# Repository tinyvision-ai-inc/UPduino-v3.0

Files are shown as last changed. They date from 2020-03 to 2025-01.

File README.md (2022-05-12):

# UPduino-v3.0 and 3.1

UPduino v3.0 Front

Image credit: Gregory Benjamin

## UPDuino v3.1: PCB Design Files, Designs, Documentation

The UPDuino v3.1 is a small, low cost FPGA board. The board features an on-board FPGA programmer, flash and LED with _all_ FPGA pins brought out to easy to use 0.1" header pins for fast prototyping.

The tinyVision.ai UPduino v3.x Board Features:

* Lattice UltraPlus ICE40UP5K FPGA with 5.3K LUTs, 1Mb SPRAM, 120Kb DPRAM, 8 Multipliers
* FTDI FT232H USB to SPI Device
* _ALL_ 32 FPGA GPIO on 0.1” headers
* 4MB SPI Flash
* RGB LED
* On board 3.3V and 1.2V Regulators, can supply 3.3V to your project
* Open source schematic and layout using KiCAD design tools
* Integrated into the open source [APIO toolchain](https://github.com/FPGAwars/apio)
* Works with [IceStudio](https://github.com/FPGAwars/icestudio)<sup>[nightly/dev branch only at the moment](https://downloads.icestudio.io/)</sup>

Please see the [wiki page](https://github.com/tinyvision-ai-inc/UPduino-v3.0/wiki) for the changes that were implemented from v2.1. Some salient features are:
* 4 layer board with a solid ground plane, proper layout/decoupling for good signal integrity and FPGA operation
* Access to on-board 12MHz oscillator using a jumper
* _All_ FPGA pins including LED driver pins are brought to 0.1" headers
* qSPI Flash capable
* tinyFPGA bootloader compatible 

Here are some resources for you:
* [Documentation](https://upduino.readthedocs.io/) (beyond what's on this GitHub)
* [Discord channel](https://discord.gg/3qbXujE)
* [Schematic](./Board/v3.0/UPduino_v3.0.pdf)
* [AssemblyDrawing](./Board/v3.0/UPduino_v3.0Assembly.html)
* [Blinking LED](./RTL/blink_led)
 
TinyVision.ai blog posts:
* [Magic Smoke and PTC's](https://blogs.tinyvision.ai/upduino/power/ptc/2021/12/31/magic-smoke-and-PTCs.html)
* [Lattice Modelsim on Windows](https://blogs.tinyvision.ai/modelsim/windows/linux/radiant/lattice/2022/01/01/Using-Lattice-Modelsim-on-Win-Linux.html)
* [Ground trampolines and Phase Locked Loops](https://tinyvision.ai/blogs/processing-at-the-edge/ground-trampolines-and-phase-locked-loops)

You can buy this board here:
US and non-EU orders: . 

EU Orders with VAT paid: 

For expedited shipping options, please visit the storefront at www.tinyvision.ai or email us directly at: sales at tinyvision dot ai.

## Useful links
* [Digi-Key Intro to FPGA Video series](https://youtube.com/playlist?list=PLEBQazB0HUyT1WmMONxRZn9NmQ_9CIKhb)
* [osresearch](https://github.com/osresearch/up5k): large collection of very useful code and a good overview.
* [UPduino FPGA tutorial using APIO](https://blog.idorobots.org/entries/upduino-fpga-tutorial.html)
* [A very detailed blog on implementing a RISCV in the FPGA](https://pingu98.wordpress.com/2019/04/08/)
* [Lattice iCECube2 tutorial](https://hsel.co.uk/2018/05/21/lattice-ice40-ultra-plus-fpga-gnarly-grey-upduino-tutorial-1-the-basics/)
* [Open FPGA verilog Tutorial](https://github.com/Obijuan/open-fpga-verilog-tutorial/wiki)

## The next generation of Upduino (coming soon)
* [pico-ice](https://github.com/tinyvision-ai-inc/pico-ice)

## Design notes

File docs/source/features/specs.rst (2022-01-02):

Specifications
================

The UPduino supports the following features:
  - Lattice iCE40 UP5K UG48 FPGA

UPduino Pinout
--------------
The UPduino pinout was kindly provided by Xark below.
  - G0/G1/G3/G6 refer to Global clock inputs.
  - gpio_20 is used for the on-board 12MHz oscillator if the OSC jumper is shorted.
  - gpio_35 is the ideal location to supply a clock as this will allow placement of the PLL right next to it.
  - If gpio_35 is used as an input, y nything other than a clock, you cannot use a PLL in your design!
  - qSPI flash access is possible by shorting the jumpers on the board: note that this uses up gpio_10 and gpio_20.
::

                  PCF  Pin#  _____  Pin#  PCF
                       ------| USB |------
                 <GND> |  1   \___/   48 | spi_ssn   (16)
                 <VIO> |  2           47 | spi_sck   (15)
                 <RST> |  3           46 | spi_mosi  (17)
                <DONE> |  4           45 | spi_miso  (14)
      <RGB2>   led_red |  5           44 | gpio_20   <N/A w/OSC, G3>
      <RGB0> led_green |  6     U     43 | gpio_10
      <RGB1>  led_blue |  7     P     42 | <GND>
                 <+5V> |  8     D     41 | <12 MHz>
               <+3.3V> |  9     U     40 | gpio_12
                 <GND> | 10     I     39 | gpio_21
               gpio_23 | 11     N     38 | gpio_13
               gpio_25 | 12     O     37 | gpio_19
               gpio_26 | 13           36 | gpio_18
               gpio_27 | 14     V     35 | gpio_11
               gpio_32 | 15     3     34 | gpio_9
      <G0>     gpio_35 | 16     .     33 | gpio_6
               gpio_31 | 17     0     32 | gpio_44   <G6>
      <G1>     gpio_37 | 18           31 | gpio_4
               gpio_34 | 19           30 | gpio_3
               gpio_43 | 20           29 | gpio_48
               gpio_36 | 21           28 | gpio_45
               gpio_42 | 22           27 | gpio_47
               gpio_38 | 23           26 | gpio_46
               gpio_28 | 24           25 | gpio_2
                       -------------------

Errata
======
Please note that the silkscreen on the UPduino 3.0 has a bug. The GND and 12MHz clock pins are exchanged.
(Pins 41 and 42 in the drawing above). The drawing above is correct and the silkscreen is wrong for these
2 pins.

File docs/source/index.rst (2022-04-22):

.. this is a comment, it is not rendered
   when adding new *.rst files, reference them here
   in this index.rst for them to be rendered and added to the
   table of contents

=====================
UPduino Documentation
=====================

tinyVision.ai
*************

UPDuino v3.0: PCB Design Files, Designs, Documentation
------------------------------------------------------

The UPDuino v3.0 is a small, low-cost FPGA board. The board features an on-board FPGA programmer, flash and LED with _all_ FPGA pins brought out to easy to use 0.1" header pins for fast prototyping.

The tinyVision.ai UPduino v3.0 Board Features:

* Lattice UltraPlus ICE40UP5K FPGA with 5.3K LUTs, 1Mb SPRAM, 120Kb DPRAM, 8 Multipliers
* FTDI FT232H USB to SPI Device
* _ALL_ 32 FPGA GPIO on 0.1” headers
* _ALL_ FTDI pins brought to test points
* 4MB SPI Flash
* RGB LED
* On board 3.3V and 1.2V Regulators, can supply 3.3V to your project
* Open source schematic and layout using KiCAD design tools
* Integrated into the open source `APIO toolchain <https://github.com/FPGAwars/apio>`_

Please see the `wiki page <https://github.com/tinyvision-ai-inc/UPduino-v3.0/wiki>`_  for the changes that were implemented from v2.1. Some salient features are:

* 4 layer board with a solid ground plane, proper layout and decoupling for good signal integrity and FPGA operation
* Access to on-board 12MHz oscillator using a jumper (short R16)
* _All_ FPGA pins including LED driver pins are brought to 0.1" headers
* qSPI flash capability
* tinyFPGA bootloader compatible

Useful links:

* `osresearch <https://github.com/osresearch/up5k>`_: large collection of very useful code and a good overview.
* `UPduino FPGA tutorial using APIO <https://blog.idorobots.org/entries/upduino-fpga-tutorial.html>`_
* `A very detailed blog on implementing a RISCV in the FPGA <https://pingu98.wordpress.com/2019/04/08/>`_
* `Digi-Key FPGA Playlist <https://youtube.com/playlist?list=PLEBQazB0HUyT1WmMONxRZn9NmQ_9CIKhb>`_: "What is an FPGA" all the way to designing a risc-v custom peripheral in just 12 videos filled with great tutorials, links, and explanations.

TinyVision.ai blog posts:

* `Magic Smoke and PTC's <https://blogs.tinyvision.ai/upduino/power/ptc/2021/12/31/magic-smoke-and-PTCs.html>`_
* `Lattice Modelsim on Windows <https://blogs.tinyvision.ai/modelsim/windows/linux/radiant/lattice/2022/01/01/Using-Lattice-Modelsim-on-Win-Linux.html>`_
* `Ground trampolines and Phase Locked Loops <https://tinyvision.ai/blogs/processing-at-the-edge/ground-trampolines-and-phase-locked-loop>`_

.. toctree::
   :hidden:

   self
   
.. toctree::
   :maxdepth: 2
   :caption: Introduction
   :hidden:

   introduction/introduction

.. toctree::
   :maxdepth: 2
   :caption: Getting Started
   :hidden:

   getting_started/tool_installation
   getting_started/first_steps
   getting_started/verilog_resources
   
.. toctree::
   :maxdepth: 2
   :caption: Features
   :hidden:

   features/specs
   
.. toctree::
   :maxdepth: 2
   :caption: Tutorials
   :hidden:
   
   tutorials/blink_led.rst
   tutorials/bank_voltages
   tutorials/oscillator
   tutorials/disconnect_tricolor_led
   tutorials/fpga_sram_programming
   tutorials/qspi_flash
   tutorials/tinyfpga
   tutorials/riscv
   tutorials/open_ocd
   tutorials/pmod
   tutorials/adding_slave_select_to_fpga

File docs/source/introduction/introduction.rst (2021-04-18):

Introduction
============

The UPduino 3.0 is a highly capable device. We will get started with setting it up, and the "hello world" of this FPGA, getting an LED to blink!

First Steps
-----------

First things first, after ensuring your board is functioning and shows up as a USB device, the tools need to get installed. There are two paths to do:

- APIO or icetools (For MacOS, Linux, and Windows)
- Lattice Radiant (Linux and Windows only)

To install these tools, please go to the "Tool Installation" document!

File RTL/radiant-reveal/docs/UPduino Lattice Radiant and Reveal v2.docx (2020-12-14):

UPduino v3.0 Lattice Radiant and Reveal v2.2 Setup With Debug Cable

The following document is a quick set-up guide for the UPduino v3.0 FPGA programming board. The purpose of this document is to show how to set up the RGB blinky verilog file with the Lattice v2.2 toolchain plus running an example debug session using the Reveal v2.2 tools.

All files and example project files have been provided – it could be necessary to change some of the files to fit the directory structure the examples are downloaded/cloned into – this is OS and tool dependent to some extent. The demo programs here were all run under Win10-64.

It is assumed the UPduino v3.0 git repository has been downloaded to a local directory as well as what is contained in this demo document and the corresponding directories. To get started under Radiant – it is necessary to set up a project and to make some small changes to the rgb_blink.v file – if you have downloaded/cloned the files – but if you are following along and want to make your own local changes – diagrams/pictures have been provided that will hopefully make it easy. If you haven’t gone through the Lattice tutorial document – it will more than likely be helpful to take a look at that – plus it will be referenced in this document a few times - Lattice Radiant Software Tutorial for iCE40 UltraPlus¹ – the download link is here (if this can’t be found – then ‘google’ the title):
https://www.latticesemi.com/media/LatticeSemi/Documents/InstallationGuides/Radiant20_Tutorial_ice40.ashx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

Please refer to the above tutorial for the finer details on creating a new project – it would be good to review even if you have cloned the project and are trying to run it for the first time. If you have cloned the project and the assumption is that you have – the project you want to open is:

<your dir>/UPduino-v3.0/RTL/Lattice-Radiant-Project-v2p2/rgb_blinky/rgb_blinky.rdf

The first thing to note are a few changes are necessary to run the RGB demo code:

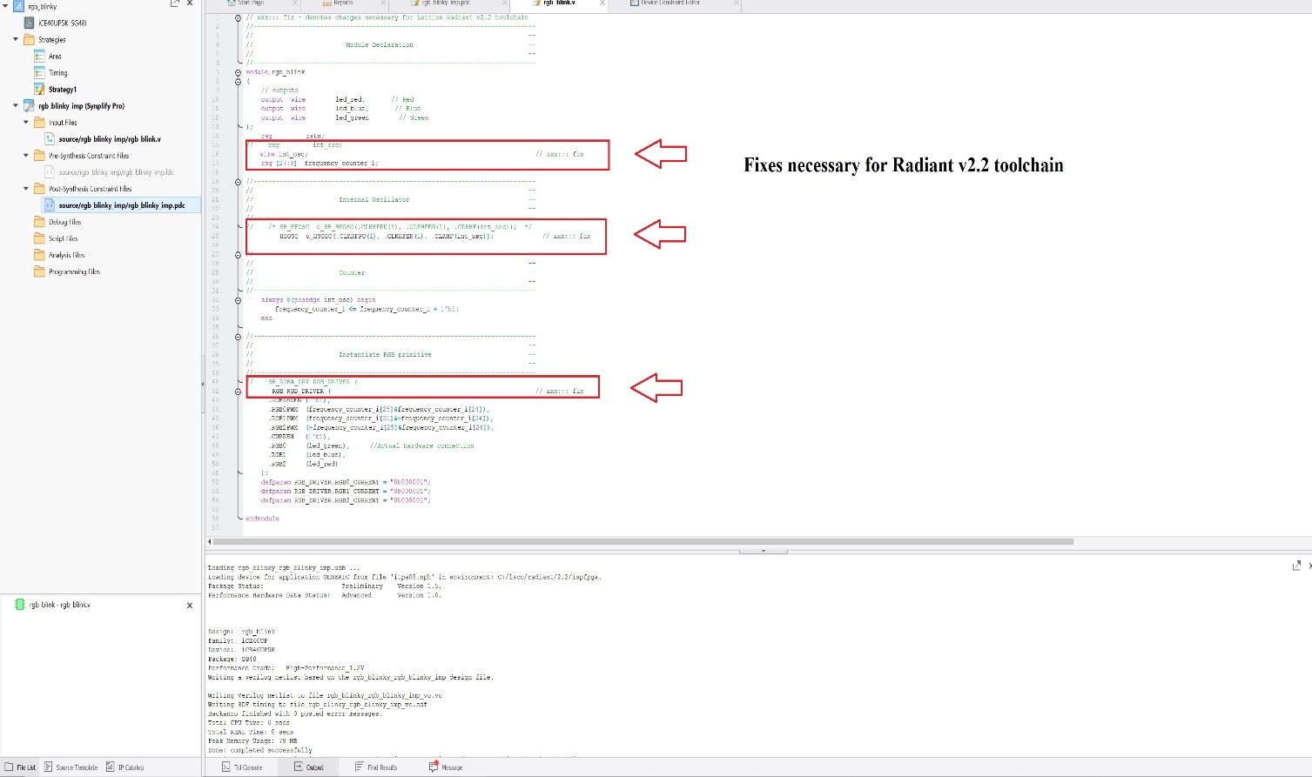
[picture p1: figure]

Figure 1 – Necessary verilog updates to run demo program in Lattice Radiant.

Note the changes outlined in Figure 1 are suggestions – but for the purposes of this demo please make sure that your verilog file has those updates or it will not build (under the Lattice Radiant tools).

Please make sure the project builds OK without error. There is an example constraints file included in the example project directory.

We want to be able to run the Reveal debugger – for purposes of this demo, the debug cable used is the FTDI C232HM USB 2.0 HI-SPEED TO MPSSE CABLE².

This cable should be able to be used as received from FTDI – the only real difference I have seen thus far is setting the drive current to 8 milli-amps for the I/O pins. The xml file for the FTDI cable is included in the git repository just in case. The FTDI cable can be viewed here:

https://www.ftdichip.com/Products/Cables/USBMPSSE.htm and PDF:
https://www.ftdichip.com/Support/Documents/DataSheets/Cables/DS_C232HM_MPSSE_CABLE.pdf

Using this cable is cheaper than the HW-USBN-2B³:

https://www.latticestore.com/searchresults/tabid/463/searchid/1/searchvalue/hw-usbn-2b/default.aspx - plus it is available – Mouser P/N: 895-C232HM-DDHSL-0
and current cost is $35.00 (USD) (as an example of a cheaper option).

Please refer to pages 38 - ~ 44 of the tutorial for any questions regarding the following – the first step is to add debug logic to our design using the Reveal Inserter:

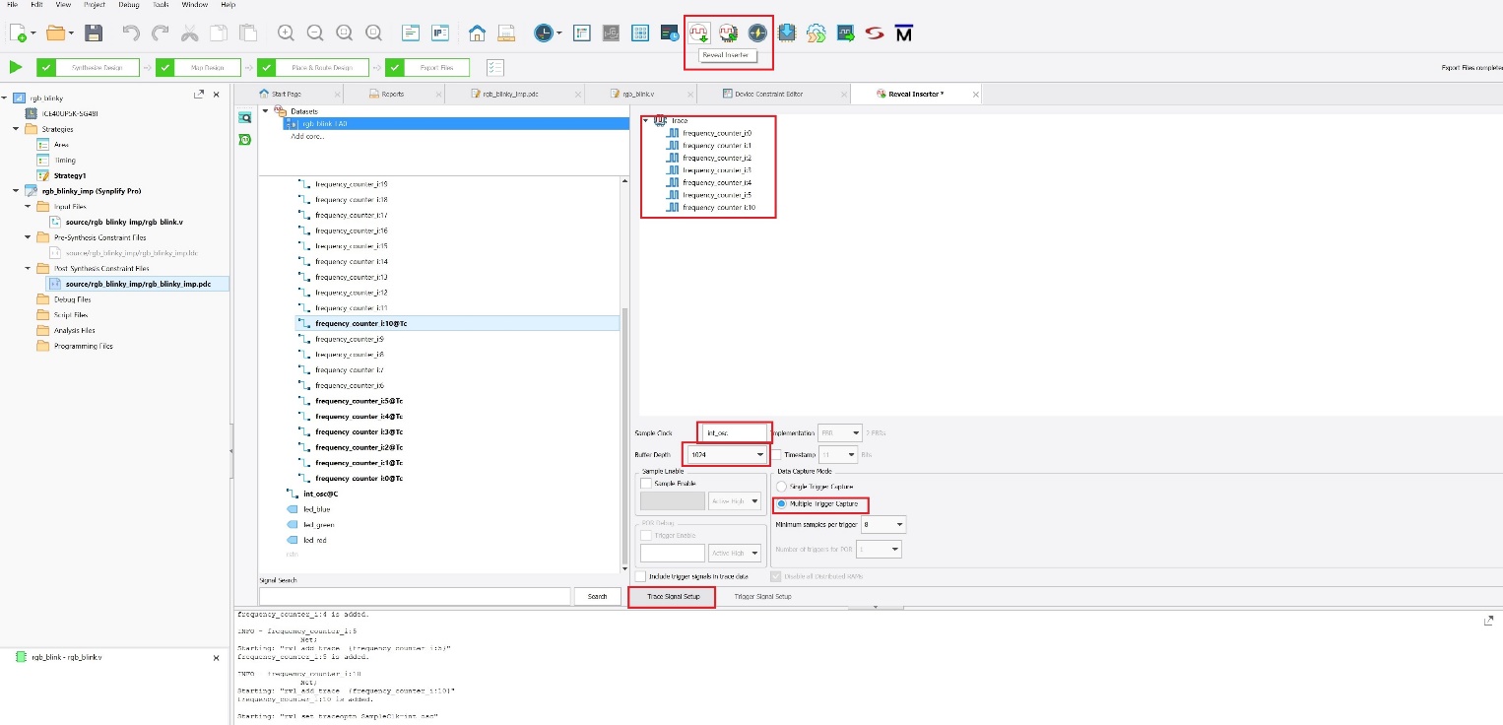
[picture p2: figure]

Figure 2 – Using Reveal Inserter to add on-chip Debug Logic.

Once the desired trace signals have been added – trigger signals need to be added:

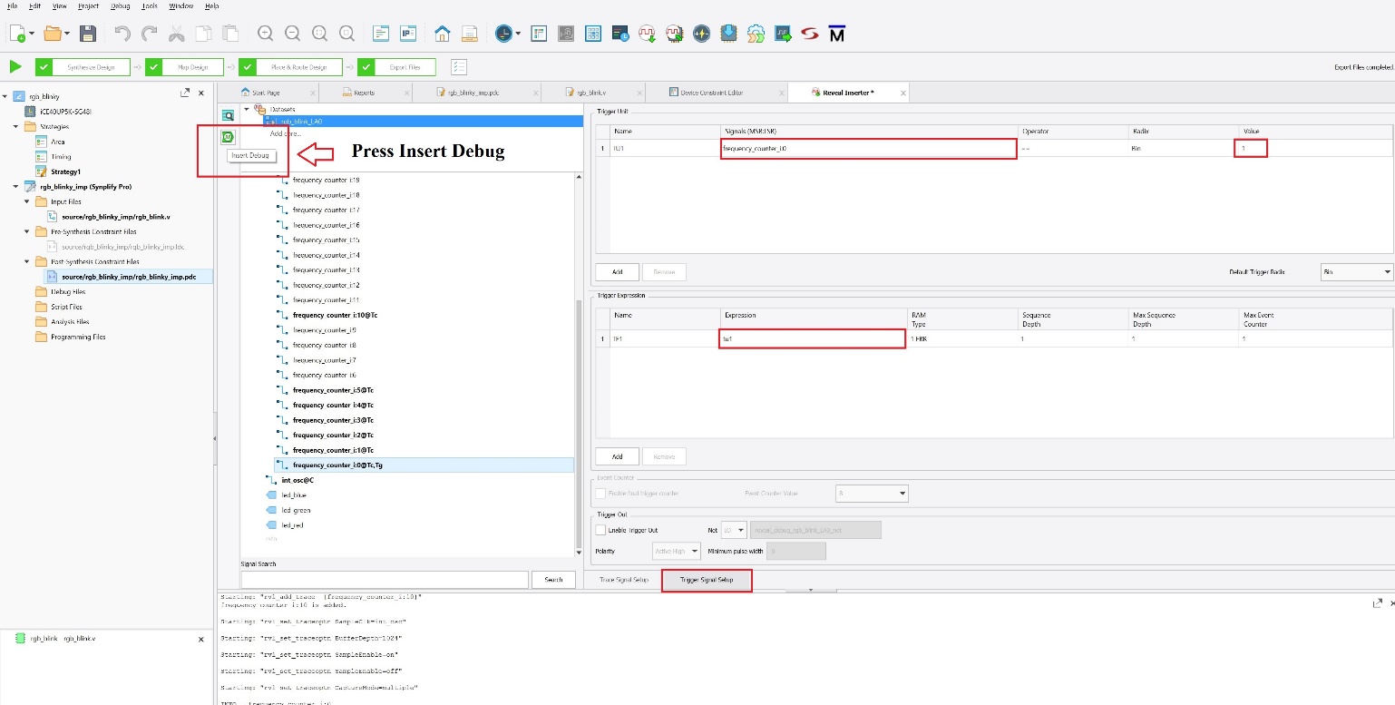
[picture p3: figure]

Figure 3 – Adding trigger signals to the Reveal Inserter set up for on-chip Debug Logic.

To add to the project – press the Insert Debug Icon as shown in Fig. 3.

Once that is added – make sure the project can build. Once the project has built with no errors – then the JTAG connections need to be checked. The Lattice tools will set the JTAG pins even if they are not in the constraints file – but subsequent builds could reassign the pin locations – so it is a good idea to try and lock those down – otherwise you will be moving the JTAG pins every time you make a change and rebuild.

In the Device Constraints Editor – you can type in the pin number to override what the tools have assigned if it does not match the constraints file or what you have used for your JTAG pins. Make sure and connect GND first when connecting the FTDI cable to the UPduino board.

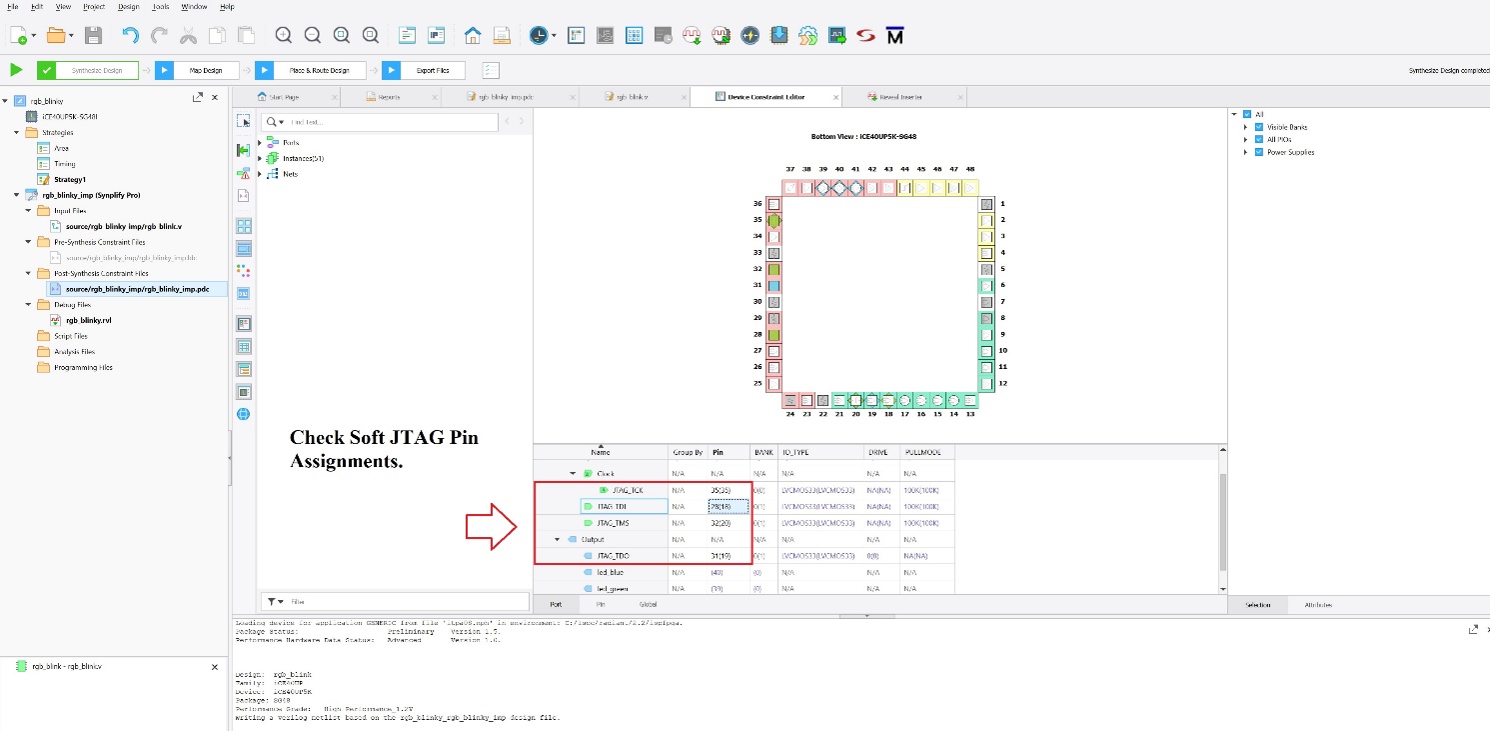
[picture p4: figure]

Figure 4 – Check the Soft JTAG Pin Assignments.

If you must update the JTAG pin assignments – you will have to rebuild to make sure the JTAG pins are assigned to the pin numbers used for the JTAG FTDI cable. Otherwise, a cable server error will appear (when making the connections – we’re not quite ready for this now – but as this is a potential issue – it’s better to bring it up sooner than later) and it’ll tell you to check items 9-1 (Failure Points) in the following document:
Reveal Troubleshooting for Lattice Radiant Software⁴
https://www.latticesemi.com/view_document?document_id=52931

The cable used in this demo is FTDI, UART, MPSSE (Multi-Protocol Synchronous Serial Engine), using the standard VCP driver from FTDI. (Please note document mentioned earlier in this document².) If the proper cable is being used – then errors encountered at this step where Reveal complains about the cable server not being able to open the USB port is more than likely an incorrect JTAG connection – and it can be caused by the tools moving the JTAG ports around if they are not locked down – so double check the JTAG port pin assignments *EVERY* time you build.

Once the project has been built and the pin assignments have been verified and you have connected your debugger –

Note you can refer to P. 43 of the tutorial document for a quick explanation on how to connect the debug cable to a target board – here we are connecting an FTDI cable to the UPduino v3.0 – but the procedure is essentially the same.

The build needs to be downloaded to the target:

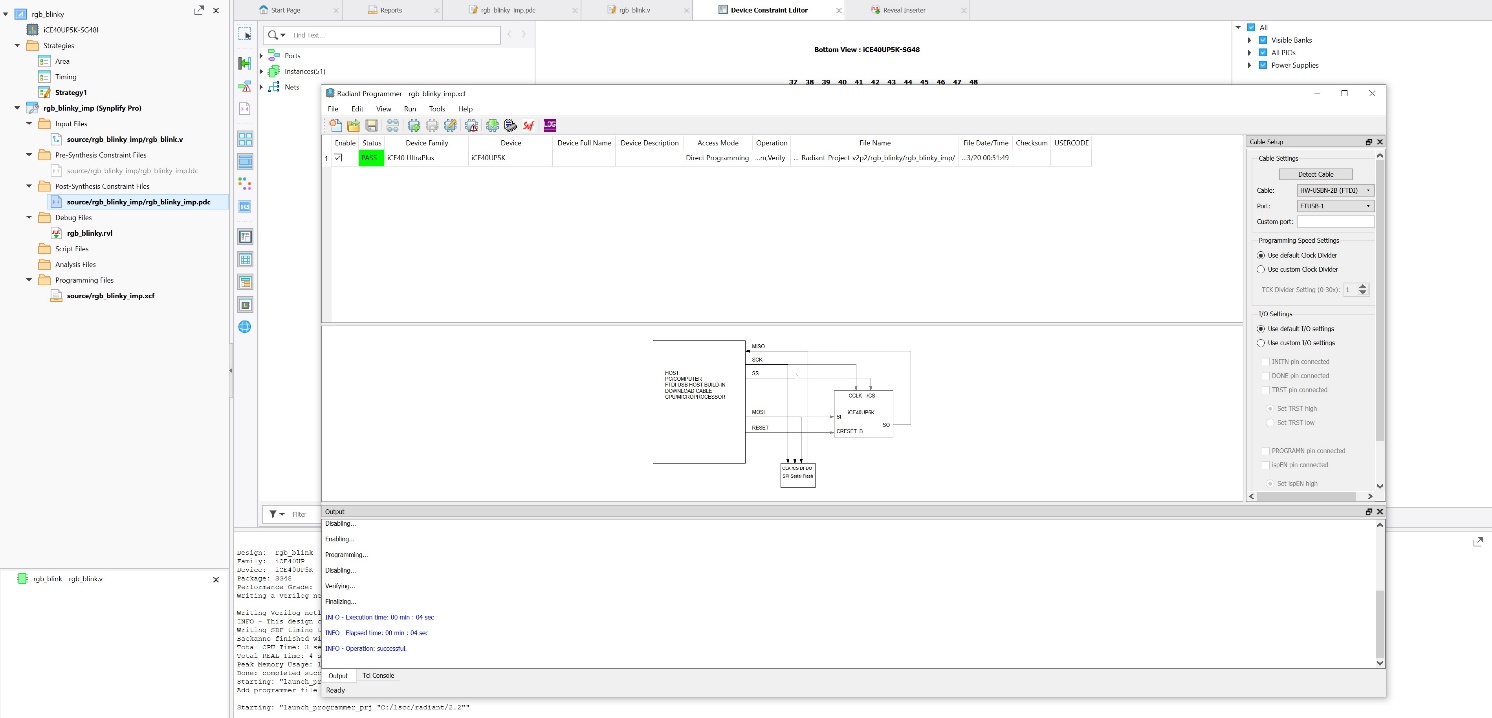
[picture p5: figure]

Figure 5 – Program the target board with the rgb_blink.v build plus on-chip debug logic.

For the next steps you can refer to pages 44 - ~48 of the tutorial document.

Once the target has been programmed – open the Reveal analyzer to create the debug analyzer session:

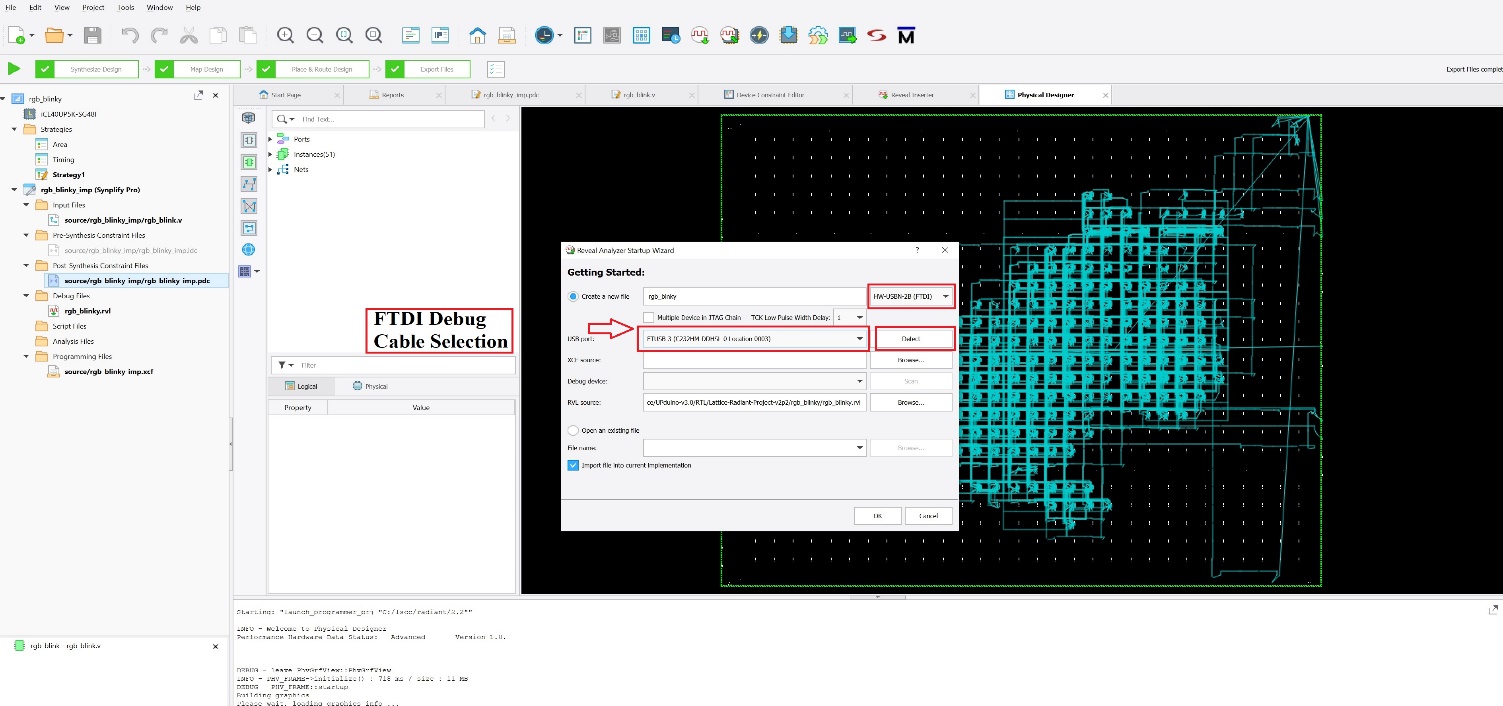
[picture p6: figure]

Figure 6 – Creating Reveal Analyzer Session

Refer to Figure 6 regarding creating the Reveal Analyzer session – make sure the correct FTDI cable is selected for the debug session.

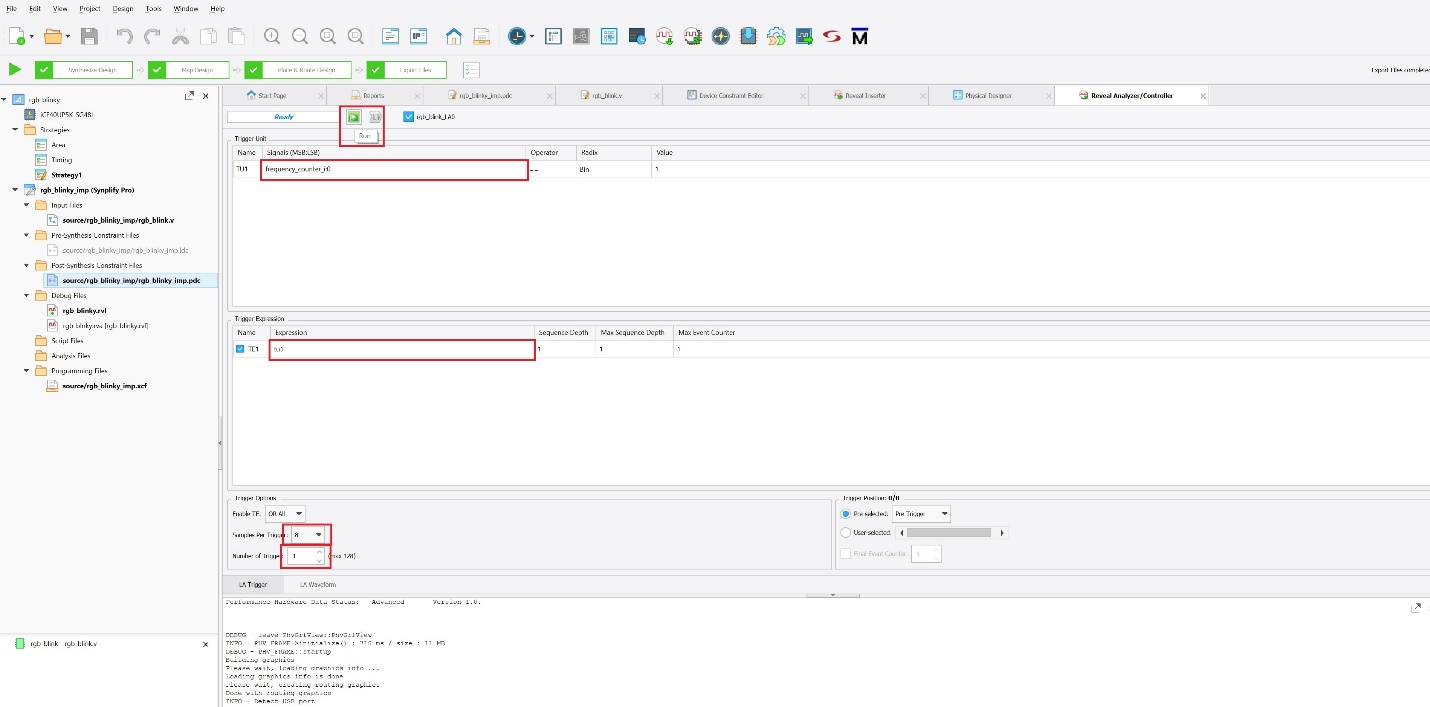
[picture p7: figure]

Figure 7 – Reveal Analyzer Window

Refer to Figure 7 regarding the Reveal Analyzer Window – the green box with the arrow can be pressed to run the analyzer session – note ‘Ready’ should be visible to the left of that window.

If an error pops up – please refer to the troubleshooter link mentioned previously – but errors are more than likely due to incorrect JTAG connections.

Once the Reveal Analyzer runs – you should see something like:

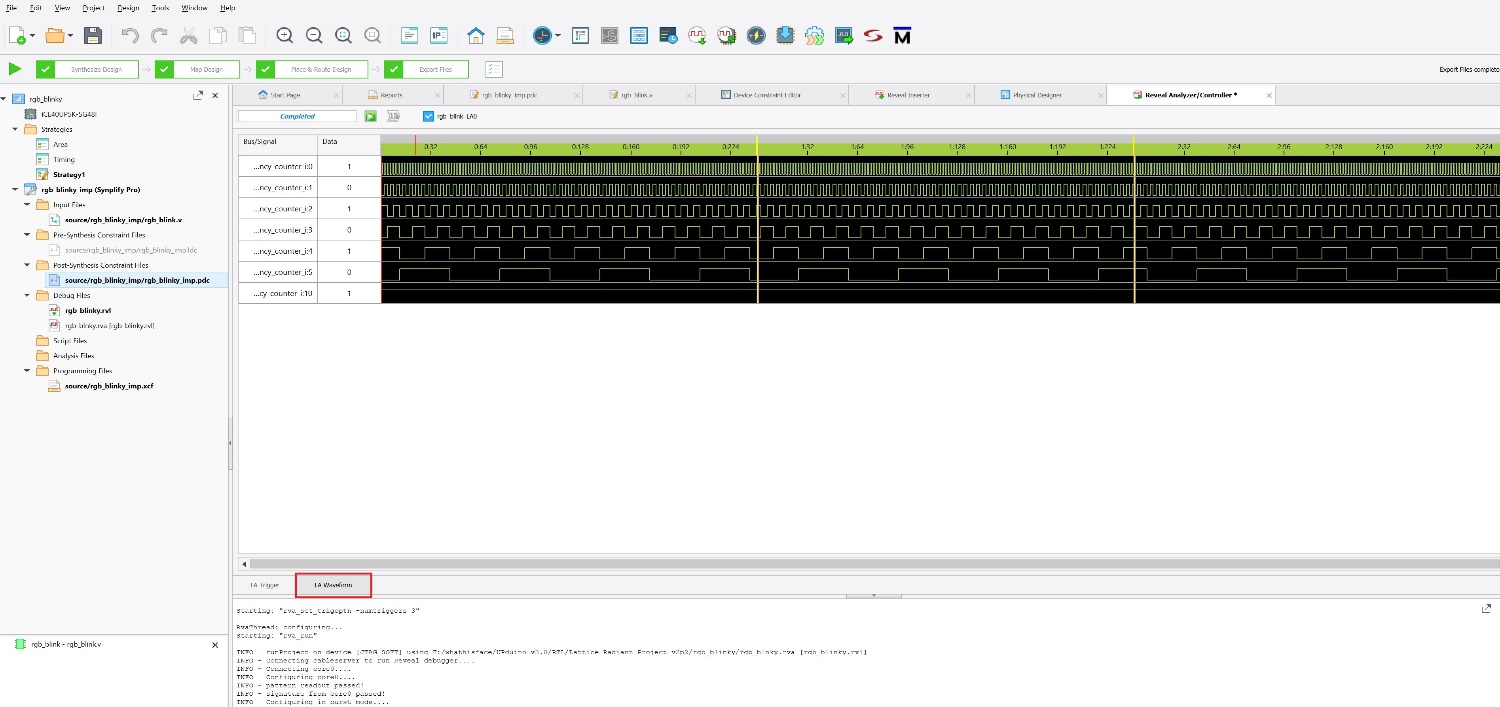
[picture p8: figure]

Figure 8 – Reveal Analyzer Session Results

Hopefully, this brief guide has been helpful in running a JTAG debug session on the UPduino v3.0 FPGA board and will serve as a handy reference.

References:

(1) Lattice Radiant Software Tutorial for iCE40 UltraPlus
https://www.latticesemi.com/media/LatticeSemi/Documents/InstallationGuides/Radiant20_Tutorial_ice40.ashx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

(2) FTDI C232HM USB 2.0 HI-SPEED TO MPSSE CABLE
https://www.ftdichip.com/Products/Cables/USBMPSSE.htm and PDF:
https://www.ftdichip.com/Support/Documents/DataSheets/Cables/DS_C232HM_MPSSE_CABLE.pdf

(3) LATTICE HW-USBN-2B Programmer
https://www.latticestore.com/searchresults/tabid/463/searchid/1/searchvalue/hw-usbn-2b/default.aspx

(4) Reveal Troubleshooting for Lattice Radiant Software
https://www.latticesemi.com/view_document?document_id=52931

whathisface@protonmail.com 2

UPduino v3.0 Lattice Radiant and Reveal v2.2

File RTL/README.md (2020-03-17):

# FPGA build instructions
The FPGA can be built either using the Lattice Radiant toolchain that can be downloaded [here](http://www.latticesemi.com/en/Products/DesignSoftwareAndIP) or the open source icestorm toolchain which can be downloaded [here](https://github.com/cliffordwolf/icestorm).

## Instructions for icestorm toolchain programming
Programming the board using icestorm can be done using the following command:

    iceprog.exe -d i:0x0403:0x6014 <bitfile name>

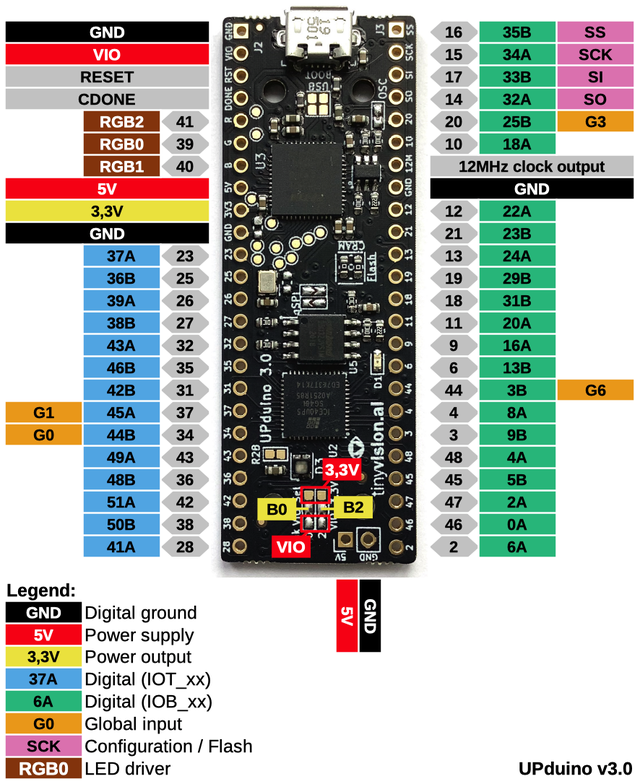
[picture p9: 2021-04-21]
docs/source/features/upduino_pinout.png

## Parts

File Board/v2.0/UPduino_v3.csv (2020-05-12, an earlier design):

Item | Qty | Reference(s) | Value | Footprint | Datasheet | MPN
1 | 13 | C1, C11, C19, C20, C21, C22, C24, C27, C28, C29, C30, C31, C35 | 4.7u | Capacitor_SMD:C_0603_1608Metric | ~
2 | 17 | C2, C3, C5, C6, C7, C8, C9, C10, C12, C13, C14, C15, C16, C17, C18, C25, C36, C4 | 0.1u | Capacitor_SMD:C_0603_1608Metric | ~ | C1005X5R0J104K050BA
5 | 1 | D1 | LTST-C191KGKT | LED_SMD:LED_0603_1608Metric | ~
6 | 1 | D2 | 1N4148WT-7 | Diode_SMD:D_SOD-523 | https://www.vishay.com/docs/85748/1n4148w.pdf
7 | 1 | D3 | CLMVC-FKA-CLBDGL7LBB79353 | VS.preety:LED_Cree-PLCC4_2x2mm_CW | ~
8 | 3 | FB1, FB2, FB3 | BLM18HE152SN1D | Inductor_SMD:L_0603_1608Metric | ~
11 | 1 | J1 | 47589-0001 | vs:USB_Micro_AB_Female_0475890001 | ~
15 | 1 | R1 | 2.2K | Resistor_SMD:R_0603_1608Metric | ~
16 | 1 | R3 | 12K | Resistor_SMD:R_0603_1608Metric | ~
17 | 3 | R4, R17, R18 | 10K | Resistor_SMD:R_0603_1608Metric | ~
18 | 5 | R5, R8, R9, R14, R15 | 10K | Resistor_SMD:R_0603_1608Metric | ~
19 | 1 | R6 | 100 | Resistor_SMD:R_0603_1608Metric | ~
20 | 1 | R7 | 2.2K | Resistor_SMD:R_0603_1608Metric | ~
23 | 2 | R12, R13 | 0 | Resistor_SMD:R_0603_1608Metric | ~
27 | 1 | U1 | 93LC56BT-I/OT | vs:SOT-23-6 | http://ww1.microchip.com/downloads/en/DeviceDoc/20001749K.pdf
28 | 1 | U2 | ICE40UP5K-SG48ITR | Package_DFN_QFN:QFN-48-1EP_7x7mm_P0.5mm_EP5.6x5.6mm | http://www.latticesemi.com/Products/FPGAandCPLD/iCE40Ultra
29 | 1 | U3 | FT232H | vs:QFN-48-1EP_8x8mm_P0.5mm_EP6.2x6.2mm | http://www.ftdichip.com/Products/ICs/FT232H.htm
30 | 1 | U4 | SG-210STF 12.0000ML3 | vs:Oscillator_SMD_Abracon_ASDMB-4Pin_2.5x2.0mm | https://abracon.com/Oscillators/ASDMB.pdf
31 | 1 | U5 | W25Q32JVSSIM | Package_SO:SOIC-8_5.23x5.23mm_P1.27mm | http://www.winbond.com/resource-files/w25q32jv%20revg%2003272018%20plus.pdf
32 | 1 | U6 | AP2127K-3.3 | vs:SOT-23-5 | https://www.diodes.com/assets/Datasheets/AP2127.pdf
33 | 1 | U7 | AP2127K-1.2 | vs:SOT-23-5 | https://www.diodes.com/assets/Datasheets/AP2127.pdf
34 | 1 | U8 | SN74AUP2G125DCUR | Package_SO:VSSOP-8_2.3x2mm_P0.5mm | http://www.ti.com/lit/sg/scyt129e/scyt129e.pdf

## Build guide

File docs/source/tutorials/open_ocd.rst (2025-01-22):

How to use the UPduino as an OpenOCD or JTAG debugger?
====

Please see this repo for details on how to use teh FPGA for level translation as well as a spring loaded pogo adapter that can be used to easily probe a board.

https://github.com/tinyvision-ai-inc/upduino-jtag

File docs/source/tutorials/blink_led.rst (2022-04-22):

Blinking an LED
===============

Blinking an LED on the UPduino 3 is its "hello world"

Getting Started
----

The sample code to blink an LED is built-in to this repository! 

https://github.com/tinyvision-ai-inc/UPduino-v3.0

Go to RTL > blink_led folder, to see the example.

Running the Code
-----------------

The code can easily be run! First, make sure the UPduino is plugged in.

If you want to run the code using icetools (iceprog, specifically), type: ``make``

Then: ``iceprog rgb_blink.bin``

You should see the LED blink!

If you want to use apio, first type: ``apio init --board upduino3``

Then: ``apio verify`` to make sure your code works, and then finally:

``apio build`` and ``apio upload``

The LED should blink now!

Making Changes
--------------

So the LED is (hopefully) blinking now. If you want to change the code or learn how it works, open the rgb_blink.v file

*.v stands for Verilog, a low-level programming language*

The code runs asynchroniously, meaning that multiple lines can run at once on the board.

Anyways, **tinker around with the code!** Some things to do:

  - Make it blink a different color
    - Maybe white? Yellow? A random hex value?
  - Make it blink in a different interval
   - Make it go fast
   - How about slow?
   - Can the LED stay on a solid color?
  - Try different brightness values
    - How bright can it go? How many levels are there?
    - Can you do a "breathing" effect, where the LED eases in and out of brightness?
    
There are endless possibilities with this board! Getting an LED to blink is just the start...

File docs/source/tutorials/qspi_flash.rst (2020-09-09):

How to enable qSPI flash for _much_ higher flash throughput (up to 8x!)
====

The UPduino flash is a qSPI/DTR capable device. ie. it is capable of operating with four IO's instead of a single IO and also using both edges of the clock, effectively giving 8x the bandwidth on the SPI bus. In an actual use case, this bandwidth increase will only happen for burst read/writes.

Note that this is not the default as the primary requirement was for the UPDuino to be 100% backward compatible. If qSPI mode were made the default, some of the designs that used the two extra pins required for qSPI would not work.

The layout makes special  arrangements to allow for this mode of operation of the flash by shorting R24/R25 in the schematic below:

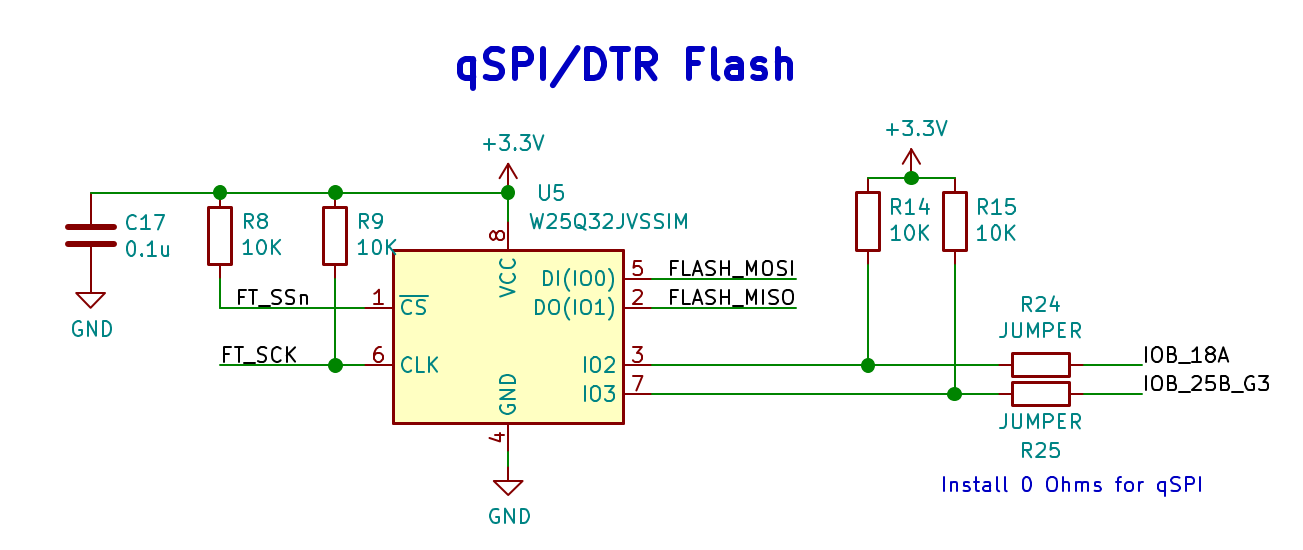
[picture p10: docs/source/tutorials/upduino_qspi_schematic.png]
UPduino qSPI connection schematic


The corresponding portion of the layout is labelled qSPI for clarity and should be shorted as shown.

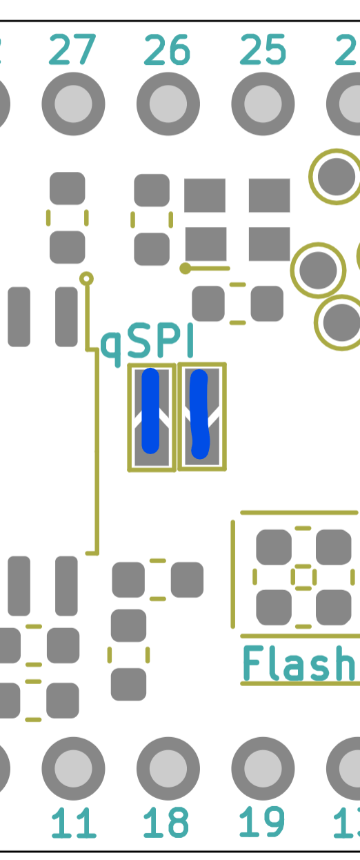
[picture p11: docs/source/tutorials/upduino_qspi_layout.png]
UPduino qSPI connection layout


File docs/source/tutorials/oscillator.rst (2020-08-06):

How to use the oscillator options on the UPduino?
====

The UPduino has an on-board oscillator that generates 12MHz. This clock is generated by an oscillator and distributed to the FTDI, an external pin and also to a global buffer on the FPGA via an optional jumper. 

The pin IOB_25B_G3 was chosen specifically as it is already in a bank thats forced to be at 3.3V levels. If any other global capable IO were to be used, this would force that IO bank to not be capable of the full flexibility of IO voltages.

The schematic portion is captured below:

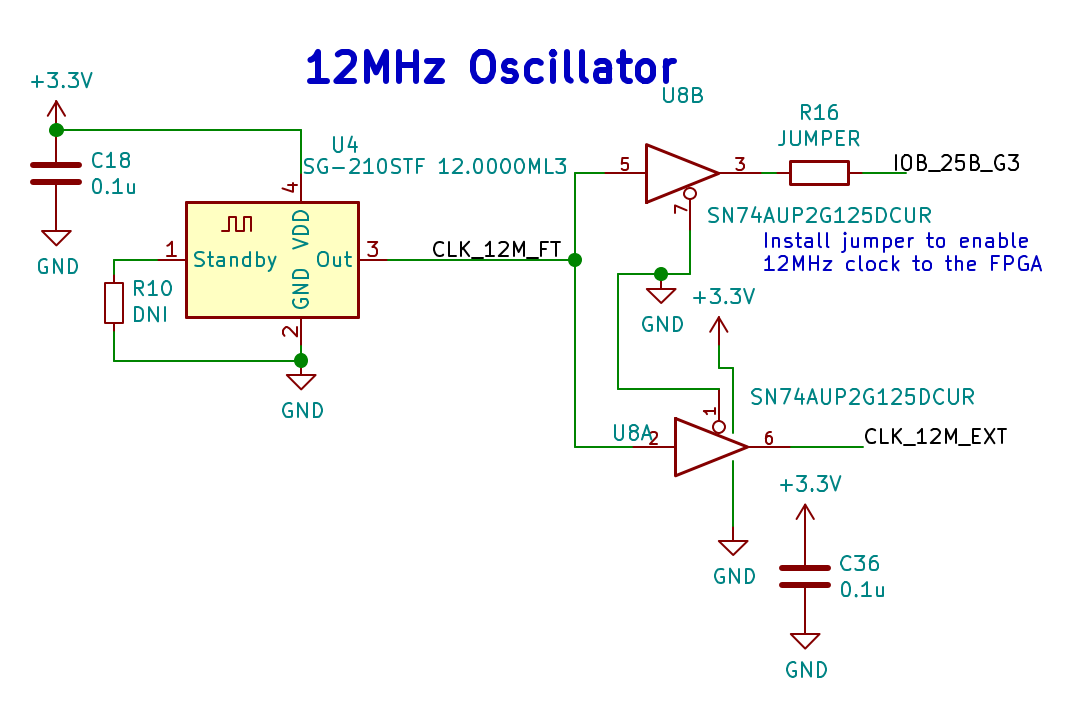
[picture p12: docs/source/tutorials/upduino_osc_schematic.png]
UPduino oscillator schematic


The 12MHz can be routed to the FPGA directly on the board to preserve signal quality and also to minimize external connection by shorting R16. Note that this marked as OSC on the silkscreen for clarity.

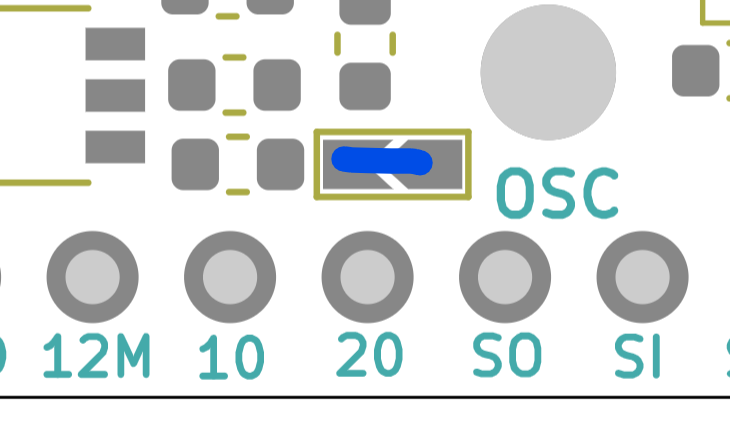
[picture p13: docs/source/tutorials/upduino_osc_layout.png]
UPduino oscillator layout


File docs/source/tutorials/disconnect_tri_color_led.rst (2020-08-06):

How to disconnect the 3 color LED so you can use the pins for your own PWM experiments?
====

The 3 color LED can be disconnected from power to allow the use of the 3 pins from the FPGA for user purposes such as driving an external PWM sink, utilizing the programmable current sources for say a current signalling scheme or simply GPIO.

The following schematic shows the LED drive circuit where R28 can be disconnected to completely disable the LED. Note that R28 is a short on the board and so will need to be cut.

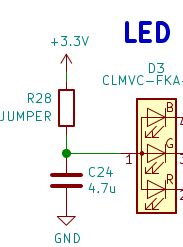
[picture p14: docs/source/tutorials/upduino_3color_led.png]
UPduino FPGA bank connections


The corresponding board section is shown below. Cut the shorting trace on R28 to disable the 3 color LED.
 
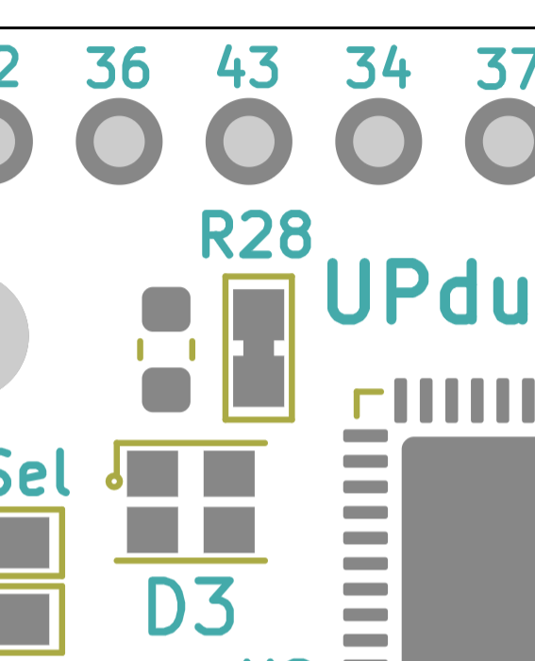
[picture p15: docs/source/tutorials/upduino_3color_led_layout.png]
UPduino FPGA bank connections


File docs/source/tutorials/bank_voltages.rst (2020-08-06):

How to connect the two banks in the FPGA to a voltage other than 3.3V?
====
The FPGA on the UPduino v3 has 3 banks hooked up as follows:

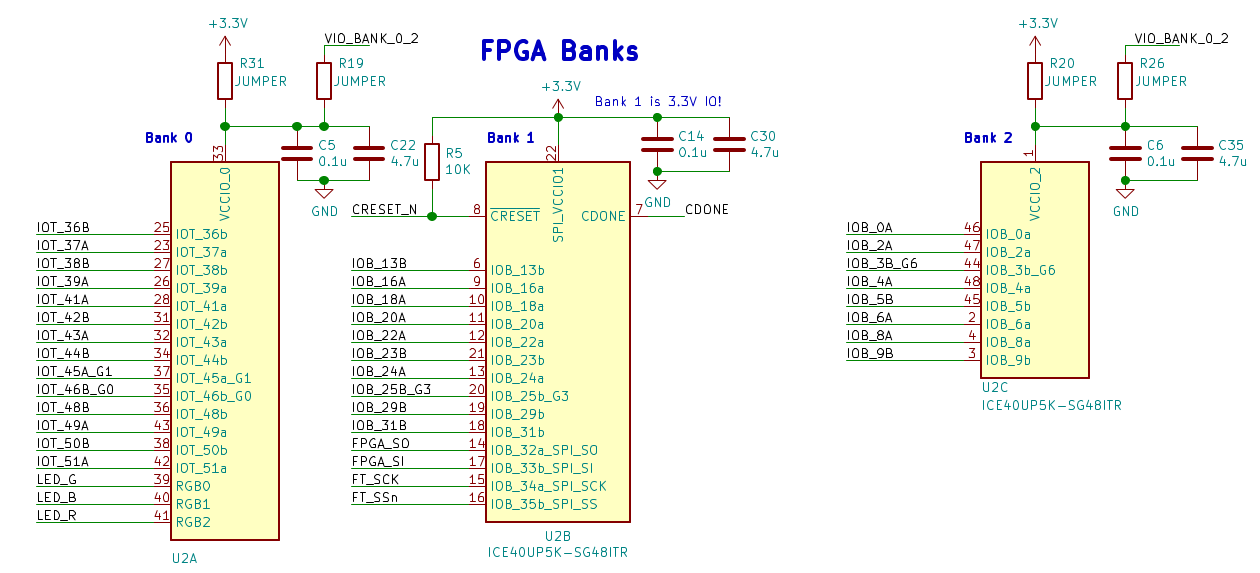
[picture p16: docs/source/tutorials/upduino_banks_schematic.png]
UPduino FPGA bank connections


Bank 1 is connected to the 3.3V supply and cannot be modified since it is hooked up the the Flash and the FTDI parts, both of which are 3.3V devices.

Bank 0 and Bank 2 however, can be changed to source/sink voltages at any arbitrary voltage within the Lattice FPGA IO specification by the following scheme in this part of the board:

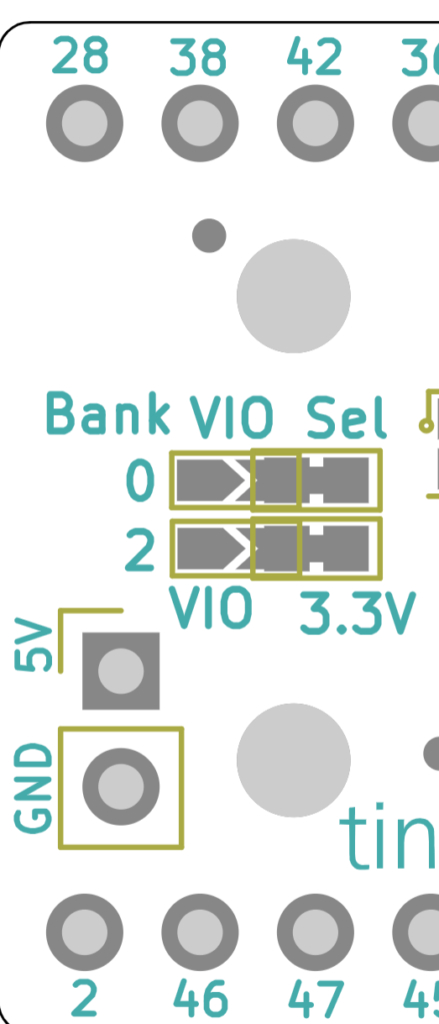
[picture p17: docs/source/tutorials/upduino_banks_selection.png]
UPduino FPGA bank connections


Bank 0:
----
Cut the trace for R31 (shorted on the board) and solder across R19.

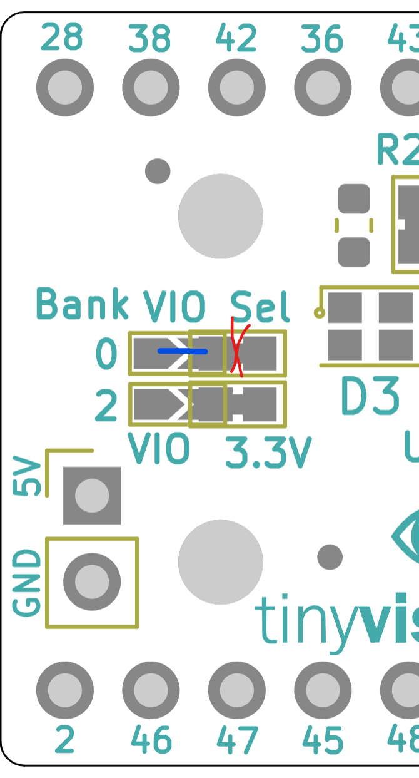
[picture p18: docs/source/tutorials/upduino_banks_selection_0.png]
UPduino FPGA bank connections


Bank 2:
----
Cut the trace for R20 (shorted on the board) and solder across R26.

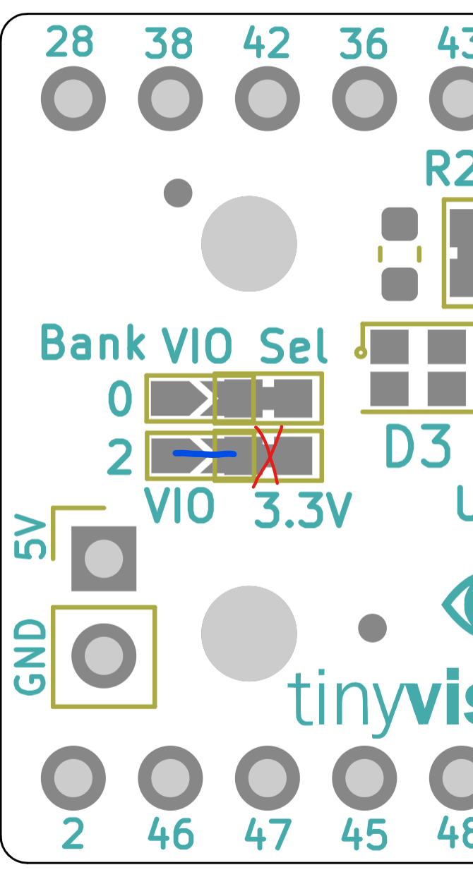
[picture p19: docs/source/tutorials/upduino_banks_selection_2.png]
UPduino FPGA bank connections


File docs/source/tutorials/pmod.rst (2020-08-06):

How to connect a PMOD device to the UPduino?
====

The UPduino pinout is setup specifically so that connecting to a 3.3V PMOD device is very easy. The pins in the following region of the UPduino are laid out per the PMOD specification allow you to interface directly to any single PMOD peripheral.

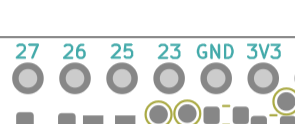
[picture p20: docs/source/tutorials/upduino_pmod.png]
UPduino PMOD connection


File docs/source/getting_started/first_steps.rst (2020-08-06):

First Steps
====

1. When you receive your UPduino, make sure it works properly before you proceed further! A simple way to do this is to plug the UPduino into a standard micro USB cable attached to a standard USB power supply such as a computer or a phone charger. 
  - You should see the green LED (D1) light up and also the 3 color LED go through a Red, Blue Green sequence. 
  - Also, if you are on a computer, you should see a new USB device called the "UPduino 3.0" show up in your list of USB devices. 
  - The board shows up as a serial port (COMxx on windows and /dev/ttyxx on Linux and Mac).
2. Download the toolchain of choice: Lattice Radiant and/or icestorm/apio.
3. Download the git repository for the UPduino and go the RTL/blink_led directory.
4. Test your toolchain installation:
  - apio/icestorm toolchain:
    - Type in "make" and this should create a bin file to be uploaded to the UPduino. 
    - For Windows, you will need to install Zadig and go through the process of switching the UPduino to the libusbk driver so that iceprog can see this. An alternative is to install the iceprog tool for windows and use that for programming instead of the icestorm version, some instructions are on [this forum](https://forum.1bitsquared.com/t/official-win10-instructions-missing/73).
    - Program the UPduino and ensure the green (D1) LED lights up and the 3 color LED starts cycling through its sequence.
5. Fiddle with the code!

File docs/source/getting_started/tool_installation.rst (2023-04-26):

Tool Installation
=================

The UPduino can use an FPGA image generated from either the open source Icestorm/APIO/OSS-CAD-Suite toolchains or the Lattice Radiant tools.

OSS-CAD-Suite/Icestorm Tool Installation
---------------------------

You can follow the instructions to install the icestorm toolchain from various links on the web. Some are listed below for reference:

- https://github.com/YosysHQ/oss-cad-suite-build/releases (Full stack of open source tools related to FPGA development)
- https://github.com/FPGAwars/toolchain-icestorm/wiki

APIO installation
-----------------

APIO is a powerful open source ecosystem for FPGAs. To install it, use pip, and go:
``pip install apio``

As the UPduino is fairly new, however, this release does not include the software to include the UPduino 3. Thus, you will need to manually configure it. Dowload the newest commit of APIO from here: https://github.com/FPGAwars/apio

To find out where pip installed apio on your system, go:
``pip show apio``

Go there, open the apio folder, and replace its contents (but not the folder itself) with the contents of the "apio" folder in the downloaded commit of the apio directory. **Note:** If you would like to be able to easily update it, as apio is frequently updated due to its open sourse nature, you can use Git.

Note, this process of replacement is limited to pip. If you use a different package manager, refer to where it stores its downloaded and installed packages.

Lattice Radiant Installation
-----------------------------
You can follow instructions from the Lattice website to install Radiant. Note that this tool only support Linux and Windows.

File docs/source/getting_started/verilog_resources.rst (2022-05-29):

Resources related to FPGA's and HW languages
==============================================
Heres a list of resources to learn all about FPGA's and HW languages. Many have been contributed by UPduino users, thank you!

FPGA's
--------
- `FPGA4fun <https://www.fpga4fun.com>`_.
- `8 bit Workshop <https://8bitworkshop.com>`_.
- `iCE40 Samples <https://github.com/damdoy/ice40_ultraplus_examples>`_.
- `Project F <https://projectf.io/>`_.
- `Chipverify <https://www.chipverify.com/verilog/verilog-introduction>`_.
- `AsicWorld <https://www.asic-world.com/verilog/index.html>`_.
- `open fpga verilog tutorial <https://github.com/Obijuan/open-fpga-verilog-tutorial/wiki>`_.

Tools
-------
- `Icarus Verilog <http://iverilog.icarus.com/>`_.
- `GTKWave <https://iverilog.fandom.com/wiki/GTKWave>`_.
- `Verilator <https://www.veripool.org/wiki/verilator>`_.

UPduino Examples
-------
- `XarkLabs  SystemVerilog Example <https://github.com/XarkLabs/upduino-example>` - demonstrates simulation and other aspects of a more complete software toolchain

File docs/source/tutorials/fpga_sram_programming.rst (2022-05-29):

How to program the FPGA CRAM?
====

The FPGA on the UPduino can be programmed by either programming the flash and letting the FPGA reconfigure itself after a reset (default) or by programing the FPGA under direct control of the FTDI part (CRAM programming).

The CRAM in the FPGA is volatile and so will not survive a power down. However, the programming is extremely fast (65ms) as compared to programming the Flash followed by a reset (>30 seconds). In applications where the FPGA may need to be reconfigured quickly and often such as under control of a processor, it makes sense to use the CRAM mode.

CRAM Programming Mode
----
As shown below, the default option is for R12 and R13 to be installed while leaving out R11/R27. To program the CRAM, the user must remove R12/R13 and install R11/R27.

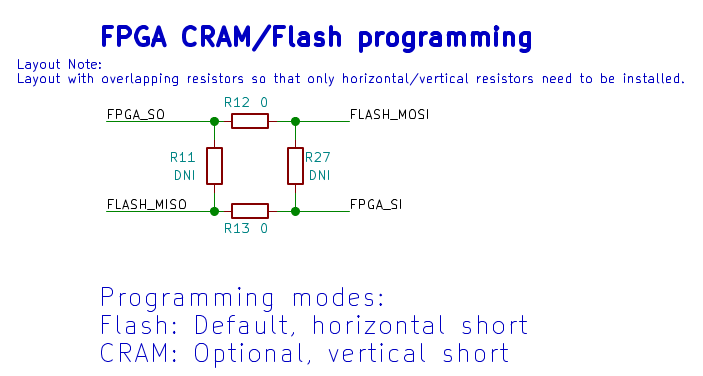
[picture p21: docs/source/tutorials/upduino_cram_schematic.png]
UPduino programming mode schematic


The default (flash) board layout is shown below:

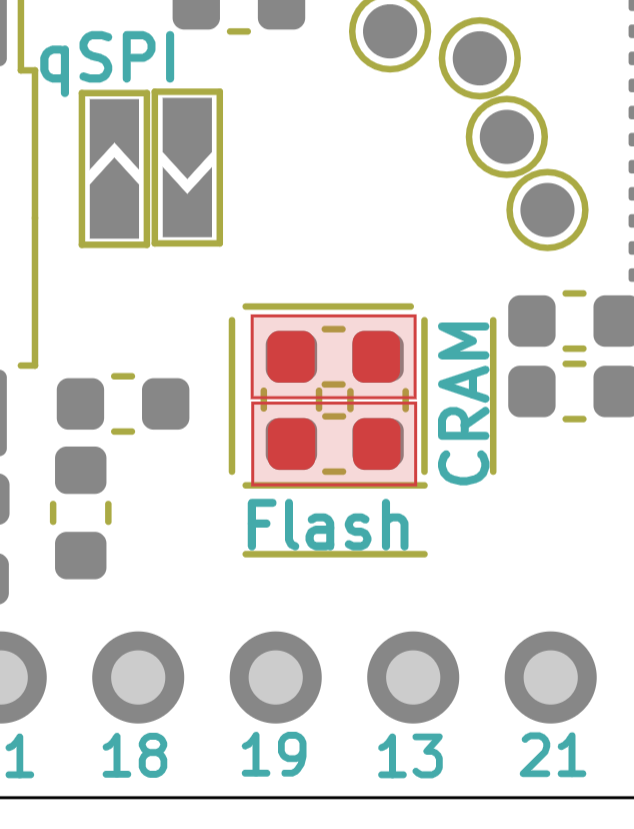
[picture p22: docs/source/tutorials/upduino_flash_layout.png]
UPduino programming mode layout (FLASH)


Removing R12/R13 and installing R11/R27 would look like the following layout:

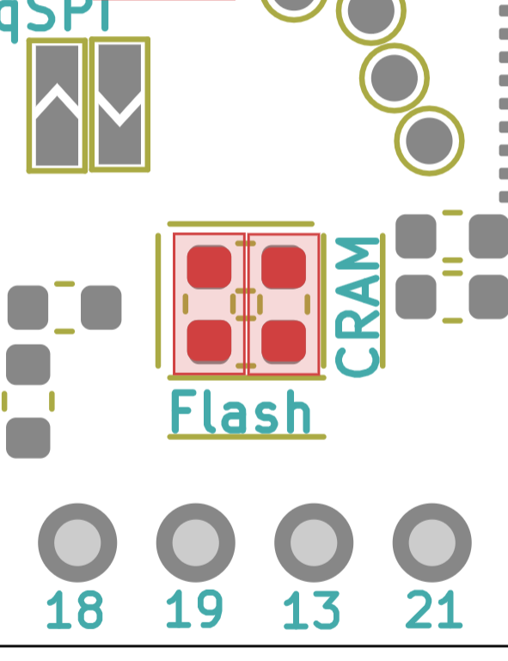
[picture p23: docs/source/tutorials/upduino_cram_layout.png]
UPduino programming mode layout (CRAM)


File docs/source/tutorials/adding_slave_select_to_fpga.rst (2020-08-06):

How to add a slave select to the FPGA from the FTDI
====

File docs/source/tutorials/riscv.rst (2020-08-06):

How to map a RISCV processor into the UPduino?
====

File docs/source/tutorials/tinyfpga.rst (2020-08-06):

How to enable the tinyFPGA bootloader support in the UPduino?
====

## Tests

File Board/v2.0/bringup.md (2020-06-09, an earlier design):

# Board Bringup

## Check voltages
| Item | Expected Value | Actual Value | Pass/Fail |
| :--- | :--- | :---  | :---  |
| Voltages | 5V | 5.041V | Pass |
|  | 3.3V | 3.306V | Pass |
|  | 2.5V | 3.090V | Need to check the FPGA spec to see if this si within the voltage specification or not. |
|  | 1.2V | 1.201V | Pass |
| External clock | 12MHz | 12MHz | Pass |
| Flash | ID: 0xEF4016 | 0xEF4016 | Pass |
| Programming | Flash | Programs | Pass |
|  | CRAM | Programs | Pass |
| LED | DONE | Lights when FPGA programs, low otherwise | Pass |
| 3 color LED | Able to get all 3 colors but see bug report below | Works | Non backward compatible, fail|
| PLL lock | Locked | TBD | Untested |

# Known bugs

## RGB LED mapping is different from the UPduino v2
The following table summarizes this bug which will be fixed in the production version of the board.
|SB_RGBA Port | v2 | v3 |
| :--- | :--- | :---|
| RGB0 | Green| Red |
| RGB1 | Blue | Green|
| RGB2 | Red  | Blue|

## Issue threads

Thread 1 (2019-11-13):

Task list for UPduino 3.0

vr2045, 2019-11-13:
- [ ] Switch to KiCAD

# Board layout:
- [ ] 4 layer board, solid ground plane, dedicated power layer for 3.3V and 1.2V distribution
- [ ] Any optional bridges must be done using special bridge-type footprint instead of resistors to make modification easy
All passives to be no smaller than 0603 footprint
- [ ] Fix silkscreen so its easy to read, add Pb Free, WEEE symbol, "Made in USA"
- [ ] Move Micro USB connector inboard a little bit to allow clean depanelization
# Power
- [ ] Dedicated power and ground planes
- [ ] Minimum of 10uF bulk capacitance on all power rails: USB, 3.3V, 1.2V
- [ ] Dedicated decoupling capacitance on each FPGA pin placed close the FPGA pin
- [ ] Power decoupling per FTDI recommendations (using ferrite beads)
- [ ] Change LDO's to be smaller parts, capable of 200mA max output
# Oscillator:
- [ ] 12MHz crystal oscillator to replace the resonator for stability
- [ ] Solder bridge option to connect the 12MHz oscillator to the FPGA
# Flash
- [ ] qSPI option using the currently unused pin 10, 20 (layout permitting)
- [ ] DTR capable flash to support even higher throughput
# Programming:
- [ ] Connect DONE signal to the FTDI
- [ ] FPGA CRAM programming capability
# LED:
- [ ] Smaller 3 color LED?
- [ ] Bring out the 3 color LED pins to alternate (DNI) LED footprints to allow these to be used for other applications such as IR LED's etc.
# Sample code:
- [ ] Ship with RISCV port instead of very simple blinky
# Optional
- [ ] Support for the tinyFPGA bootloader by DNI'ing the FTDI for a low-cost option

vr2045, 2019-12-23:
All the above feedback has been incorporated except for the silkscreen changes & the RISCV port.

classic-gentleman, 2019-12-23:
> All the above feedback has been incorporated except for the silkscreen changes & the RISCV port.

Really exciting development! I'm wondering though if the remaining two are to be addressed eventually; I understand you're probably testing the modifications with the customer that reported the PLL going out of phase first and foremost, but are the RISC-V and silkscreen changes planned for the 'release' version?

classic-gentleman, 2019-12-23:
Also: when should we expect to see some bitstreams?

And: Not sure if I followed correctly (didn't look up the gerbers but only the PDF printout) but are both the FTDI and the iCE40 connected to the flash with QSPI? I can't find `FLASH_M[O/I]S[I/O]` routing to the FPGA, only to the FTDI. Conversely, not seeing `IOB_18A`/`IOB_25B_G3` routing to FTDI, only to the FPGA. I am however noticing a bus switch, but it seems to just route whether CRAM or Flash is the target.

Please: What am I missing?

vr2045, 2019-12-24:
Thank you @classic-gentleman!!! I think you found a rather major bug in the schematic in the MISO/MOSI lines. Would have cost me not only $$$ but debug/re-build time etc. Will fix this and also the silkscreen while I'm at it... I have updated the PDF schematic in GitHub with the modification.
I'd like to send you a couple of the built boards as a bug bounty. If you dont mind, please send me your mailing address to sales at tinyvision dot ai.

Appreciate more sets of eyes on this! Power of open source!

- Yes, the silkscreen will get updated. Only minor changes expected. I should be able to sneak these in before I send the boards out for fab.

- RISCV port should already be there. There seem to be many floating around that are ported to the UPduino already. Since I'm maintaining the pinout for older UPduino, this should allow those ports to work with no modifications. Will add one to the Git repo when that happens.

- Bitstreams are already there :) All bitstreams meant for the UPduino from the many projects which have come up around the previous generation of this board should work with no modifications. If you see a reason why they wouldnt work, do let me know! The new additions should enable some interesting projects: external LED, qSPI for better performance, programmable IO voltage and CRAM programming.

- AFAIK, the FTDI does not support qSPI so the 2 extra flash lines for qSPI arent routed to the FTDI as you noticed.1

classic-gentleman, 2019-12-24:
This is very kind of you!

I'm contacting you through c(...)@a(...)a.com, just so you know it's me.

When I mentioned "bitstreams" I refer to some demonstrations and exploration of the new features such as qSPI and extra PWM, indeed. I find it enticing to have a collection of "hello-word-ish" streams, especially for those wetting their feet in Verilog. Going from simple blinkenlights to a full-blown CPU core is beyond encouraging!

(I'm really fond of the LED matrix in this project: https://dadamachines.com/product/doppler/; in fact I'd love to explore switching the FTDI for an inexpensive STM32F103 "Bluepill", linking their GPIOs while still routing them to the protoboarding pins. Could give us the best of all worlds if done right; but that probably requires a fifth layer not to mess up everything, though.)

As far as eyes go, count on my pair. When the new project files are published I'll make sure to study them thoroughly.

vr2045, 2019-12-26:
Fixed silkscreen with missing symbols and also the bug identified by @classic-gentleman . Thank you! Files updated and gerbers on Git now.

vr2045, 2019-12-26:
Yes, I totally agree: the blinking LED gets old pretty fast. qSPI will be exercised by the processor. The external PWM pins could be used to drive a servo perhaps so its not just an old LED? Will have to think about this some more.
At some point, I want to switch to Migen and the LiteX project, too many late night projects :)

I dont like the FTDI: its expensive and has only a single function. I'd rather replace it with an STM part like you suggest for not just programming but to build a more complete system with the processor+FPGA working together. This topic has been brought up in [this](https://github.com/icebreaker-fpga/icebreaker/issues/14) request...

RossBencina, 2020-01-09:
I'm just reviewing the schematic (UPduino.pdf). If I understand correctly, you've changed the behavior of the IO Bank power jumpers so that there are separate jumpers for VCCIO_0 and VCCIO_2. But unlike the Upduino 2.0, the options are either (1) onboard 3.3V or (2) a voltage supplied on a new edge terminal VIO_BANK_0_2.

This change suits me just fine, since I'm providing an off-board 1.8V reference, but it does create a regression for 2.0 users who want to take 1.2V from the onboard regulator, since the schematic shows no user source for 1.2V. It would be nice to at least provide a solder pad for greenwire mods.

vr2045, 2020-01-10:
Thanks for reviewing!
Are you trying to make sure that the 1.2V IO voltage is supported? I changed the IO voltage for the pads intentionally away from 1.2V and this could cause an issue for users. However, as pointed out by a user on the [UPduino Discord](https://cdn.discordapp.com/attachments/644406665596108810/659826986692116511/unknown.png) channel, the IO pads of the iCE40 are not specified for operation at 1.2V so the UPduino 2.0 with the 1.2V jumper on the IO was not correct. Also, 1.2V isnt a common IO voltage yet for most devices so not very useful even if it were within spec.

If you want the user to have access to the onboard 1.2V,  this is exposed as a test point on the bottom of the board for mfg test and can also be repurposed by the user.

I hope this addresses your questions?

RossBencina, 2020-01-11:
Yes, that addresses my questions, thank you. I did not realise that 1.2V was not a supported IO voltage,

cranphin, 2020-06-30:
Nice to see a new version of the board actually has been made :)
Other thing have been taking my time (FPGA's cost a lot of time! :) ).
Put my email in on the waitlist to get one ordered regardless, I like to put in my tiny bit of support :) Wish I could say I'll be able to do something with it, but have to find the time.. XD
Maybe I can at least update https://github.com/cranphin/updosoc with a better tutorial for it (and update it to the latest upstream).
Hackaday has done articles on the old upduino, think they might be interested in the new version? With a good risc tutorial it might have their interest, would be nice to get more people interested :)

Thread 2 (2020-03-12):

Missing UPduino3.0 lib file

paulossant, 2020-03-12:
Missing UPduino3.0 lib file in kicad board folder

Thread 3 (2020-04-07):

Add UART functionality to the UPduino

vr2045, 2020-04-07:
The current UPduino 3.0 design doesnt allow the UART to be used if the FPGA is accessing the Flash.
Designs like the RISCV use the Flash but also need access to the UART at the same time.
- Add UART (non flow controlled) access to the UPduino independent of the flash
- Keep cost the same
- Minimize use of extra pins, ideally keep this pin compatible with the UPduino 2.x

classic-gentleman, 2020-04-07:
Would you mind detailing this issue a bit more? Is it a hardware limitation of some sort, like GPIO sharing, or could it be fixed in the bitstream?

vr2045, 2020-04-07:
In the current design, the FTDI part doesnt do anything after the FPGA boots up but its UART pins (13,14) are connected to SCK and MOSI respectively which belongs to the flash. This is a HW limitation of the current design. This cannot be fixed by changes in the bitstream...

There are a couple of approaches possible here:
1. Change the FTDI part to be a dual channel FT2232HQ device as used on the iCEbreaker etc.
The FTDI part has a single channel serializer engine, unlike the FT2232 which has 2 such engines. Going to the 2 channel part is possible but significantly increases cost (>$2 BoM) and also increases board area resulting in pretty much full rerouting. As low cost is a primary ask from the community, option though used on projects like the iCE Breaker, is rejected.

2. Add digital muxes to allow the FTDI UART pins to be mux'ed when the SPI is not active.
In this approach, we would add a mux to pins 13, 14 of the FTDI part that would connect these pins to the ICE_SCK/MOSI pins when the SPI is active (SS is low) and otherwise, to a couple of FPGA pins when the SPI is inactive (SS is high).

# Which pins on the FPGA should be used?
Two pins (IOB_18A, IOB_25B_G3) were test points in UPduino v2 and so not normally used by users. This gives us 2 possible pins to use for the UART on the FPGA side.

vr2045, 2020-04-07:
A possible solution:
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
This is a minimal impact on cost since the 126 device can replace the current 2 gate part used for clock distribution. Also, from the routing point of view, this should be relatively easy.

classic-gentleman, 2020-04-07:
Might be a good a time as any to revisit the STM32 as a replacement for the FTDI.

paulossant, 2020-04-07:
Could this repository be a good starting point? https://github.com/ayushgaud/USB_Serial_Bridge

vr2045, 2020-04-07:
I like the idea of getting rid of the FTDI part, its not only expensive but also limited in functioanlity as compared to an STM32. This board is designed for various FPGA tools like the icestorm/icestudio/apio and Lattice Radiant programmer. All of these tools use the FTDI USB VID/PID signature at present to identify the presence of a valid programmer.

Do you think its kosher to use the VID/PID of the FTDI chip when the USB enumerates in the STM32 part? I think there may be legal trouble here.

My suggestion is to start a different project that uses the STM32 as the basis and push the new USB signature into at least the open source tools and then work with Lattice to enable their programmer to use this board.

Comments?

classic-gentleman, 2020-04-07:
I have no culinary issues whatsoever with impersonating an USB ID. 🤷‍♂️

In a more serious tone, interface interoperability is an explicit exemption in the copyright law as long as the reverse engineering follows the rules of clean room implementation.

And odds are many other protocols are just as supported, like plain serial comm. It's just a matter of choice. Implementing the full FTDI command set is more trouble than what's worth.

vr2045, 2020-04-07:
Got it. So what we need for full backward compatibility is a rather high bar and really doesnt add any value. I dont see the point of it except that these boards need to work with the Lattice toolchain, somethign to consider given that this is targeted at a Lattice part.
1. The tinyFPGA did away with this issue by using the Valenty USB stack in the FPGA itself and a dual stage bootloader. This _should_ be supported already in the current 3.0 design but not tested.
2. Another approach that you're suggesting is to use the STM32 as the USB interface. I really support this as the Micro will be usable for a great many things other than just programming.

classic-gentleman, 2020-04-07:
I never used Lattice's tools, I'm 100% invested in the open source toolchains. So it's a matter of figuring out the intersection of what both support and if more than a single option emerges, decide what's the best.

I don't see a single case where using STM32 as the USB interface isn't a win, and having it as a coprocessor for whatever is super welcome as well.

vr2045, 2020-04-07:
I agree with you completely @classic-gentleman. However, I dont think this belongs in the UPduino which is designed to work with whatever tools commercial/open source are out there.
If you dont mind, we can start a new Github project where we can build this from the ground up without any baggage.

Here are some related boards that do something similar:
http://ebrombaugh.studionebula.com/embedded/f303_ice5/index.html
https://github.com/tvelliott/dsp_ice
https://folknologylabs.wordpress.com/2016/08/17/the-lull-before-the-storm/

classic-gentleman, 2020-04-07:
I'm not seeing a conflict there. Am I missing something? Because as far as I can tell it's a matter of flashing the appropriate image on the STM32 so it behaves like anything we want it to be. It's not like we're missing any flexibility going this route.

vr2045, 2020-04-07:
We're in agreement that a thing with an STM32 + iCE40 would make sense. I think where we differ may be in how to move forward.

I see the requirement to be fully backwards compatible if we stick with the UPduino name. This has been codified in many places that we dont have control over as being FTDI (USB VIP/PID) + MPSSE engine using specific FTDI routines. eg. iceprog uses libftdi, Lattice tools use the same and so on.

This means we're bogged down trying to ensure everyone who uses the tools today are kept happy which means re-implementing the FTDI commands (which I think we agree is a waste of time). In order to get to a stable backward compatible state, a tremendous amount of testing, debug and support is going to be required, resulting in an FTDI clone (of course, with other capabilities) which is not the main aspect of the project. IMHO, this would be the first STM SW deliverable in order to say we have something thats an UPduino.

Wouldnt it be faster to develop if we called it something else (ARMistiCE? :) ) so we can start from scratch and use whatever protocol makes the best sense to communicate with the host machine & program FPGA's (drag/drop, command line using UART/USB etc.)?

This device could implement the FTDI protocol at some point in the future to take advantage of the current ecosystem if that makes sense to do (I'm not convinced this is required BTW).

classic-gentleman, 2020-04-07:
The name alone had me sold. For the love of _deity_ let's register that organisation and feel free to add me there!

vr2045, 2020-04-07:
:) I created a project with that name and added you with write access.
My suggestion is to agree on clear goals and then move forward...

paulossant, 2020-04-07:
Can i provide some help? I know stm32 toolchain and now starting with fpga boards.

vr2045, 2020-04-07:
Sure, that would be great! I started a wiki for the project so we can put our thoughts down, agree on it and move forward. I added you as a contributor as well.
I can create a discord channel for this on my [discord server](https://discord.gg/hJ98Zbk) as well so we can have real time discussions instead of this sort of delayed github chatter.

classic-gentleman, 2020-04-07:
> Can i provide some help? I know stm32 toolchain and now starting with fpga boards.

Any helping hand is welcome! I'd be especially interested in loading bitstreams via UF2. Something for interfacing with the FPGA for debugging would be nice as well, but I'm not experienced in much beyond OpenOCD...

vr2045, 2020-04-08:
Any comments on the attached schematic to allow the UART functionality that this thread was originally about to work?
## SPI operation
Whenever the SSN line goes active (low), it will enable the normal signal route.

## UART operation
When the SSN line is inactive (high), the FTDI SCK(UART_TXD) and MOSI (UART_RXD) get hooked up to alternate pins on the FPGA and the SPI-Flash signals to the FPGA/Flash get isolated so they dont combine with the UART.
[UPduino_v3.0.pdf](https://github.com/tinyvision-ai-inc/UPduino-v3.0/files/4451670/UPduino_v3.0.pdf)

classic-gentleman, 2020-04-08:
To be honest I didn't look at the schematic in detail because I don't have a clear idea about what the issue is. SPI is supposed to be a shared bus. The slave devices are supposed to high-Z the lines when CS is not asserted. Unless we're dealing with bad citizens I fail to understand the issue.

But as mentioned I didn't take a look there. I'm going by theory. Might be the async nature of UART if there's no buffer/interrupt to signal activity back to the master.

vr2045, 2020-04-08:
OK, let me restate this, hopefully more clearly!
The UPduino can be connected to a USB for SPI and/or UART connectivity as long as the Flash pins are used for this functionality.
In situations where the flash is being accessed by the design (such as a RISCV running from flash), the UART functionality cannot be used and requires the user to connect an external UART-USB.

This is typically solved using a second channel on the FTDI. This is an expensive solution.

An alternative is to add a couple of logic gates to have this functionality which is what the schematic changes do...

bsiever, 2025-06-11:
This is a very old thread, but a solution that fits some needs with the existing hardware:
1. Boot [start.s](https://github.com/digital-logic-and-computer-design/picorv32/blob/cse260m/picosoc/start.s) from flash and have a simple bootloader process that transfers everything else (including code/constants) to RAM.  This requires an appropriately configured [linker script](https://github.com/digital-logic-and-computer-design/picorv32/blob/cse260m/picosoc/sections.lds).
2. The bootloader pivots to execution of a small [startup routine](https://github.com/digital-logic-and-computer-design/picorv32/blob/016e8d7b89135d5be9734b8c44aaebb9725f4e7c/picosoc/start.s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) in RAM, which disables the flash access, enables UART, and starts the user application (i.e., calls `main`).

All links above are for a specific configuration and provided a proof-of-concept.  They may need to be adapted for other uses.

vr2045, 2025-06-12:
Thats a great hack to get this to work with no HW changes.
The limitation is that this works for programs that fit completely into RAM. Good enough for small projects.

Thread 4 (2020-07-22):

Full-scale RISC-V SoC for ice40 up5k FPGA

stnolting, 2020-07-22:
Great work! I really like the UPduino boards!

Interested in yet another RISC-V SoC for the Board? ;)

https://github.com/stnolting/neorv32

It is a full-scale `rv32imc` + *privileged architecture* RISC-V processor with SPI, I²C, PWM, GPIO, TIMER and a Watchdog. The whole SoC perfectly fits in a ice40 up5k FPGA and runs at 22MHz (tested on UPduino v2.0). The project comes with some example programs and a bootloader capable of storing/booting an executable from the on-board FPGA configuration flash.

Best regards

vr2045, 2020-07-28:
Thats very interesting, will try it out and perhaps distribute this as part of the startup program on the board!

stnolting, 2020-07-30:
Thank you very much! :)
Feel free to contact me if you need any help.

Closed 2020-07-28.

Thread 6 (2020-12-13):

apio verify blink example

JasonMorris1, 2020-12-13:
I downloaded this repository and ran apio init --board upduino3 then apio verify

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

JasonMorris1, 2020-12-13:
I also tried on windows using the fpga-tool-chain
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

JasonMorris1, 2020-12-13:
I got it to work on windows I had to changed the makefile and delete a comment

vr2045, 2020-12-14:
I think I fixed it now... Thanks for checking and reporting it...

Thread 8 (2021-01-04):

Silkscreen swapped on J3 pins 7 and 8 (12M and GND)

radicale, 2021-01-04:
Noticed that the schematic did not match the silkscreen on LHS (J3) pins 7 and 8.  Quick test shows that the issue is with the silkscreen.

radicale, 2021-01-04:
Nevermind.  Seems like it's been already fixed in the repo.

vr2045, 2021-01-04:
Thanks for being proactive and filing this in the first place! Enjoy the
board and let me know if you need anything.

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

Closed 2021-01-04.

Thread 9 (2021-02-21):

Increase 3.3V current availability

vr2045, 2021-02-21:
The v3.0 reduced the available current from the 3.3V supply as compared to the v2. Increase the current by adding a switcher to the design to limit power dissipation while giving users the ability to draw much more power from the 3.3V supply on the board. Thanks to @bayoussef for this suggestion.

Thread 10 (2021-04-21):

Inconsistency between schematic and actual board

irdc, 2021-04-21:
Looking at the schematic vs the actual board, there appears to be an inconsistency regarding the location of the 12MHz output. From the USB connector on downwards, the pins on the board are marked as "10", "12M", "GND", "12", etc. However, according to the schematic it's "10", "GND", "12M", "12" (that is: 12M and GND are swapped).

Which is the correct one?

vr2045, 2021-04-21:
Please see the https://upduino.readthedocs.io/en/latest/features/specs.html for the pinout. Initial versions of the UPduino had a silkscreen error and the silkscreen was blacked out with a marker to avoid confusion. This should have been corrected on later versions of the board.

Closed 2021-04-21.

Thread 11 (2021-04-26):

Missing VCC pin in schematic

vr2045, 2021-04-26:
Pin 30 is not shown explicitly but is connected.
Pin 30 should be shown as a separate pin instead of an overlapping connection.

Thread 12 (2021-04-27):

Silkscreen has the Ground and 12MHz clock pins reversed

vr2045, 2021-04-27:
This needs fixing on the gerbers

vr2045, 2021-06-23:
Added documentation on the [UPduino readthedocs](https://upduino.readthedocs.io/en/latest/features/specs.html) page.

Closed 2021-06-23.

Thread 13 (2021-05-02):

No way to use FPGA as SPI slave without hacking the board or removing the EEPROM

jmlzone, 2021-05-02:
I was trying an to use the FPGA as a spi slave for booting from an external processor to load a configuration directly into the FPGA.  I realized then when I go through the boot sequence and pull SS low for the FPGA, it also pulls SS low on the SPI EEPROM.  I was hoping I could use the R11/12/13/27 jumpers, but that won't help because the flash pins are on the 3 & 4 of the board connector.  If the FPGA pins were on the board connectors ie FPGA_SI (needed) and FPGA_SO (not realy needed) instead of FLASH_MOSI and FLASH_MSIO, that would solve my issue or other jumpers to assign the board connectors 3&4 between FLASH and FPGA.

Thanks for considering this for 3.x or 4.0.
James

vr2045, 2021-05-02:
Good point. Wil implement this for the next go around, will have to make
sure this is backwards compatible as well.

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

jmlzone, 2021-05-03:
After some thought, I can up with a short term solution (for me)  I Removed the R12/R13 and installed a '2x2 header'  This allowed me to use 2 jumpers to select FLASH or SRAM or unplug and connect jumpers to the header for my use.  Unfortunately the spacing of the resistors is just under 2.5mm so its tricky to bend and surface solder the header.  Although I dislike movable jumpers as much as the next guy, this may be a good solution with minimal impact to the board layout.
Potentially to maximize flexibility and minimize build/test cost, layout with top traces shorting where r12/r13 are located but with the 4 through holes.  Send the board with the 4 through holes and the 2x2 header as a user option.

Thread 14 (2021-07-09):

silkscreen of PCB, error perhaps !

ARTS37, 2021-07-09:
Hi all,
i purchased an upduino v3 card through tindie on june 26th. I think there is a little problem with the silkscreen of PCB. Indeed there seems to be a reversal between pin 7 and pin 8 of the left J3 connector. Pin J3-7 marked CLK_12M_EXT is equipotential with the other GNDs and pin J3-8 marked GND generates a square wave of 12MHz frequency.

vr2045, 2021-07-09:
You're right, this is documented at:
https://upduino.readthedocs.io/en/latest/features/specs.html#errata

On Fri, Jul 9, 2021 at 12:33 PM Armand ROLLAND ***@***.***>
wrote:

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

vr2045, 2021-07-09:
Reopening issue so people are aware of this.

vonj, 2021-07-10:
After panicking a little, I just want to point out that the board works fine. It's just that some  markings on the board are mis-labelled.

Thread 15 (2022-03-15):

Error: board upduino3 not connected

standarddeviant, 2022-03-15:
I'm able to build and verify the `blinky_led` example with apio, but am unable to upload. I see the below error:
```
C:\Users\davec\Documents\apio\UPduino-v3.0\RTL\blink_led>apio upload
(DEBUG) Profile path: C:\Users\davec\.apio\profile.json
(DEBUG) Home_dir: C:\Users\davec\.apio
(DEBUG) Profile path: C:\Users\davec\.apio\profile.json
(DEBUG) Home_dir: C:\Users\davec\.apio
(DEBUG) Run Command: lsusb
(DEBUG) System_base_dir: C:\Users\davec\.apio\packages\tools-oss-cad-suite
(DEBUG) System bin dir: C:\Users\davec\.apio\packages\tools-oss-cad-suite\bin
(DEBUG) Executable file: C:\Users\davec\.apio\packages\tools-oss-cad-suite\bin\lsusb.exe
(DEBUG) Profile path: C:\Users\davec\.apio\profile.json
(DEBUG) Home_dir: C:\Users\davec\.apio
(DEBUG) Run Command: lsftdi
(DEBUG) System_base_dir: C:\Users\davec\.apio\packages\tools-oss-cad-suite
(DEBUG) System bin dir: C:\Users\davec\.apio\packages\tools-oss-cad-suite\bin
(DEBUG) Executable file: C:\Users\davec\.apio\packages\tools-oss-cad-suite\bin\lsftdi.exe
Error: board upduino3 not connected
```

It seems the board is connected to my machine according to `apio system --lsftdi`:
```
C:\Users\davec\Documents\apio\UPduino-v3.0\RTL\blink_led>apio system --lsftdi
(DEBUG) Profile path: C:\Users\davec\.apio\profile.json
(DEBUG) Home_dir: C:\Users\davec\.apio
(DEBUG) Run Command: lsftdi
(DEBUG) System_base_dir: C:\Users\davec\.apio\packages\tools-oss-cad-suite
(DEBUG) System bin dir: C:\Users\davec\.apio\packages\tools-oss-cad-suite\bin
(DEBUG) Executable file: C:\Users\davec\.apio\packages\tools-oss-cad-suite\bin\lsftdi.exe
Number of FTDI devices found: 1
Checking device: 0
Manufacturer: tinyVision.ai, Description: UPduino v3.1
```

I followed Shawn Hymel's FPGA tutorials on youtube (on Part 2) to get to this point. I've used Zadig to make sure `libusbK` is the selected driver for the `UPduino v3.1` board seen by Zadig.

Have others run into this error?

cliffordtech, 2022-03-16:
Hi @standarddeviant,
I also have the UPduino3.1 and have just run into exactly the same problem. Console output is virtually identical to yours. Have you been able to resolve the issue? We may have run into the error discussed in this thread: https://github.com/FPGAwars/icestudio/issues/234

vr2045, 2022-03-16:
Another possibility is that icestudio doesnt recognize the 3.1 USB string?
You can update the EEPROM quite easily:
If on windows, you can download the FTDI FT_PROG program and change the EEPROM to read v3.0 and see if that helps.
Dont worry, this wont brick your FPGA board :)

cliffordtech, 2022-03-16:
So after trying many of the suggestions in the previously linked thread without success, I decided to try accessing iceprog directly.... and it worked!

```
$apio raw "iceprog -d i:0x0403:0x6014 hardware.bin"

PATH: </snipped>

init..
cdone: high
reset..
cdone: low
flash ID: 0xEF 0x40 0x16 0x00
file size: 104090
erase 64kB sector at 0x000000..
erase 64kB sector at 0x010000..
programming..
reading..
VERIFY OK
cdone: high
Bye.
```

cliffordtech, 2022-03-16:
@vr2045 I think you got it. Updating the Product Description (under USB String Descriptors) from "UPduino v3.1" to "UPduino v3.1" and then repeating the driver update and upload process did the trick. Thank you for the pointer!

One important thing to note is that FT_PROG does not recognize the FTDI device when the libusbK driver is being used. I just moved it to a new USB port so that it reverted to the FTDIBUS driver.

`
[Tue Mar 15 21:31:24 2022] Processing upduino3

-----------------------------------------------------------------------------------------------------------------------------

iceprog -d i:0x0403:0x6014:0 hardware.bin
init..
cdone: high
reset..
cdone: low
flash ID: 0xEF 0x40 0x16 0x00
file size: 104090
erase 64kB sector at 0x000000..
erase 64kB sector at 0x010000..
programming..
reading..
VERIFY OK
cdone: high
Bye.
=============================================== [SUCCESS] Took 18.96 seconds ===============================================`

joshbrake, 2022-03-26:
I had this same issue and fixed it by changing my board in `apio.ini` file to `upduino31`. Noticed that  https://github.com/FPGAwars/apio/blob/c7c941e63220d62512df2cd203cea3f7fd8c6f27/apio/resources/boards.json#L261 includes an entry with the correct FTDI descriptor – no need to mess with the eeprom!

Xenador77, 2022-04-25:
Anyone having this same issue with icestudio, the [nightly/dev branch](https://downloads.icestudio.io/) has the updated board list with Upduino-3.1

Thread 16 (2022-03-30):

LiteX-boards support

tcal-x, 2022-03-30:
It would be great to have support (both a platform file and a target file) in [litex-boards](https://github.com/litex-hub/litex-boards/tree/master/litex_boards/targets) for v3.1.

I did find these for v1: https://github.com/timvideos/litex-buildenv/blob/master/targets/upduino_v1/base.py  (target file), https://github.com/timvideos/litex-buildenv/blob/master/platforms/upduino_v1.py (platform file).

Probably some of the pinout in the platform file would need updating, and it might need some massaging to move it to `litex-boards`.

vr2045, 2022-03-31:
Good point. Will add to the list of todo's :)

Xenador77, 2022-04-27:
Done with the GPIO pins (the easy part) just figuring out how to do the ftdi serial/spi-flash pins and the 12MHz clock.

Xenador77, 2022-07-28:
https://github.com/tinyvision-ai-inc/litex-boards
Any/all feedback is appreciated, but I have (finally) managed to get the upduino_v3 platform/target files to work with the actual upduino_v3 hardware

tcal-x, 2022-07-30:
Hi @Xenador77 , I have a v3.1 board, with pmod connector, with no modifications.    Should I expect these board files to work for me?   I tried adding LedChaser (yes even though there's just the single RGB LED), since that is usually the first sign of life of LiteX running on the board.   But I don't see any activity.   Is there a reset signal I need to toggle or something like that?

I know the build is wiring to the LED correctly, since my first attempt I used polarity=0 in the LED chaser, and the LED was just bright white.   Then I used polarity=1, and the LED is off.

Xenador77, 2022-07-30:
The files **should** work for both 3.0 and 3.1 (I've only tested with the 3.1). However, there is a small modification needed (oops):
The jumper labeled "OSC" needs to be solder bridged or gpio_20 (pin 44) needs to be connected to the 12MHz pin (pin 41)
@XarkLabs made a useful ASCII pinout diagram that better illustrates the location of the pins/jumper
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

I initially included the LedChaser in the target file, but removed it due to the brightness (although my RGB LED was pinkish-red)

tcal-x, 2022-07-31:
@Xenador77 , yeah, I agree the LED is so bright.  And you're right it's not pure white.   Quickfeather has the same blinding brightness issue.

The jumper should be easy, since I'm already using the pin header on that side (for the uart).   I just need to solder those pins.   I'll let you know how it goes.

tcal-x, 2022-07-31:
@Xenador77 , no success yet at my end.   What was the exact LiteX recipe you used?   I had tried:
```
./upduino_v3.py --build --cpu-type=vexriscv --cpu-variant=minimal --flash
```

tcal-x, 2022-07-31:
@Xenador77 , I needed to make this fix; now I see (the RGB version of) LedChaser working :)

```diff
 _io = [
     # CLK / RST
-    ("clk12", 0, Pins("35"), IOStandard("LVCMOS33")),
+    ("clk12", 0, Pins("20"), IOStandard("LVCMOS33")),

```

tcal-x, 2022-07-31:
@Xenador77 I'm not having any luck with the UART/TTY though; did it work for you?

Xenador77, 2022-08-01:
I'm working on figuring out what is going on with that right now
Just to confirm, you are using an external UART board on pins 2 and 3?
(ie FT232 or FT2232 etc. anything that does UART at 3.3v)
It may have something to do with  https://github.com/tinyvision-ai-inc/UPduino-v3.0/issues/13#issue-873805660

tcal-x, 2022-08-01:
Correct, I'm using the Digilent Pmod USBUART, but not in the pmod header, instead directly connected using jumper wires to pins 2, 3, and GND of the Upduino board.   I had tried a different usb/uart board beforehand also with no luck, but I switched to the Digilent board because it has tx/rx LEDs.   I'm not getting any data coming from the Upduino, but that could be due to anything preventing the CPU from working correctly (SPIflash etc).

I guess we can look at the schematics for Fomu and/or Icebreaker, which can read from spiflash.

Xenador77, 2022-08-01:
No luck yet on my end, tried adding
 `Misc("PULLUP")`
to the tx pin, nothing seemed to change.
I'm going to try dumping the flash to see if everything is actually writing correctly to it

tcal-x, 2022-08-01:
The Upduino schematic looks pretty much the same as Fomu's w.r.t. to the spiflash connection.

https://github.com/im-tomu/fomu-hardware/blob/master/archive/pvt/releases/pvt1/tomu-fpga-pvt1.pdf

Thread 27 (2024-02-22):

Please fix the header right/left orientation (doesn't require a new PCB spin)

zapta, 2024-02-22:
There is a general confusion of what header side is left and right. For example, if we take pin gpio_23.

In the pcf files it's listed as 'left'

```
# Normal GPIO pins, left side
set_io -nowarn gpio_23 23
```

In the schematic it's on the right header symbol

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

In the Kicad 3D rendering its on the right header.
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

Please fix it to have consistent and intuitive orientation. This can be done **with spinning a new PCB** by

1. In the schematic swap the positions of the two header symbols.

2. In the headers footprint, rotate the 3D model of the pins to be on the other side of the PCB.

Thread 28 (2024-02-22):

No current limiting resistors for the three LEDS?

zapta, 2024-02-22:
The three LEDs don't have current limiting resistors. When a LED is on, do the FPGA outputs that drive them operate within spec?

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

vr2045, 2024-02-22:
The current source is inside the FPGA and can be adjusted and is capable of
driving the LED's directly. Please see the RTL blinky to see how you can do
this.

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

zapta, 2024-02-22:
Thanks. Found it. I guess I can abstract it as a module with three binary inputs to turn the leds on/off. Will look into it.

I suggest to mention this special led requirement in the PCF file and in the schematic since it's not obvious.

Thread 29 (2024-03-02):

[Feature Request] Move the external clock input to pin 35 to allow usage of the SB_PLL40_PAD primitive.

zapta, 2024-03-02:
The **SB_PLL40_PAD** primitive requires clock_in to come from pin 35 and cannot be instantiated with the external clock connected to pin 20.  Please consider moving the external clk to pin 35 in next version.

```
$ ./icepll -p -m -i 12 -o 30

/**
 * PLL configuration
 *
 * This Verilog module was generated automatically
 * using the icepll tool from the IceStorm project.
 * Use at your own risk.
 *
 * Given input frequency:        12.000 MHz
 * Requested output frequency:   30.000 MHz
 * Achieved output frequency:    30.000 MHz
 */

module pll(
	input  clock_in,
	output clock_out,
	output locked
	);

SB_PLL40_PAD #(
		.FEEDBACK_PATH("SIMPLE"),
		.DIVR(4'b0000),		// DIVR =  0
		.DIVF(7'b1001111),	// DIVF = 79
		.DIVQ(3'b101),		// DIVQ =  5
		.FILTER_RANGE(3'b001)	// FILTER_RANGE = 1
	) uut (
		.LOCK(locked),
		.RESETB(1'b1),
		.BYPASS(1'b0),
		.PACKAGEPIN(clock_in),
		.PLLOUTCORE(clock_out)
		);

endmodule
```

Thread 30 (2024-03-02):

[Feature Request] Please have the OSC jumper connected by default.

zapta, 2024-03-02:
Having the OSC jumper connected by default will improve the out of the box experience.

Please have it connected by default in the next version, e.g. using a solder jumper footprint that can be populated with a zero ohms 0402 resistor, or even just a standard 0402 resistor footprint.

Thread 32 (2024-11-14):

Error in Schematic Description „RGB Jumper Cut“

der-schmelle2, 2024-11-14:
Please correct to „R28 Jumper Cut“.

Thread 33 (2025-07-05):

12MHz oscillator cannot connect to any PLL.

dpsiddons, 2025-07-05:
It is not possible to use the PLL devices with the current board design. The 12MHz jumper on the 3.1 board links the oscillator output to pin 20. Pin 20 is in IO block 1. The PLL devices cannot be linked to IO block 1, only to blocks 0 and 2. I worked around this problem by hard wiring pin 20 to pin 35, which is in block 0, and can connect to the PLL.

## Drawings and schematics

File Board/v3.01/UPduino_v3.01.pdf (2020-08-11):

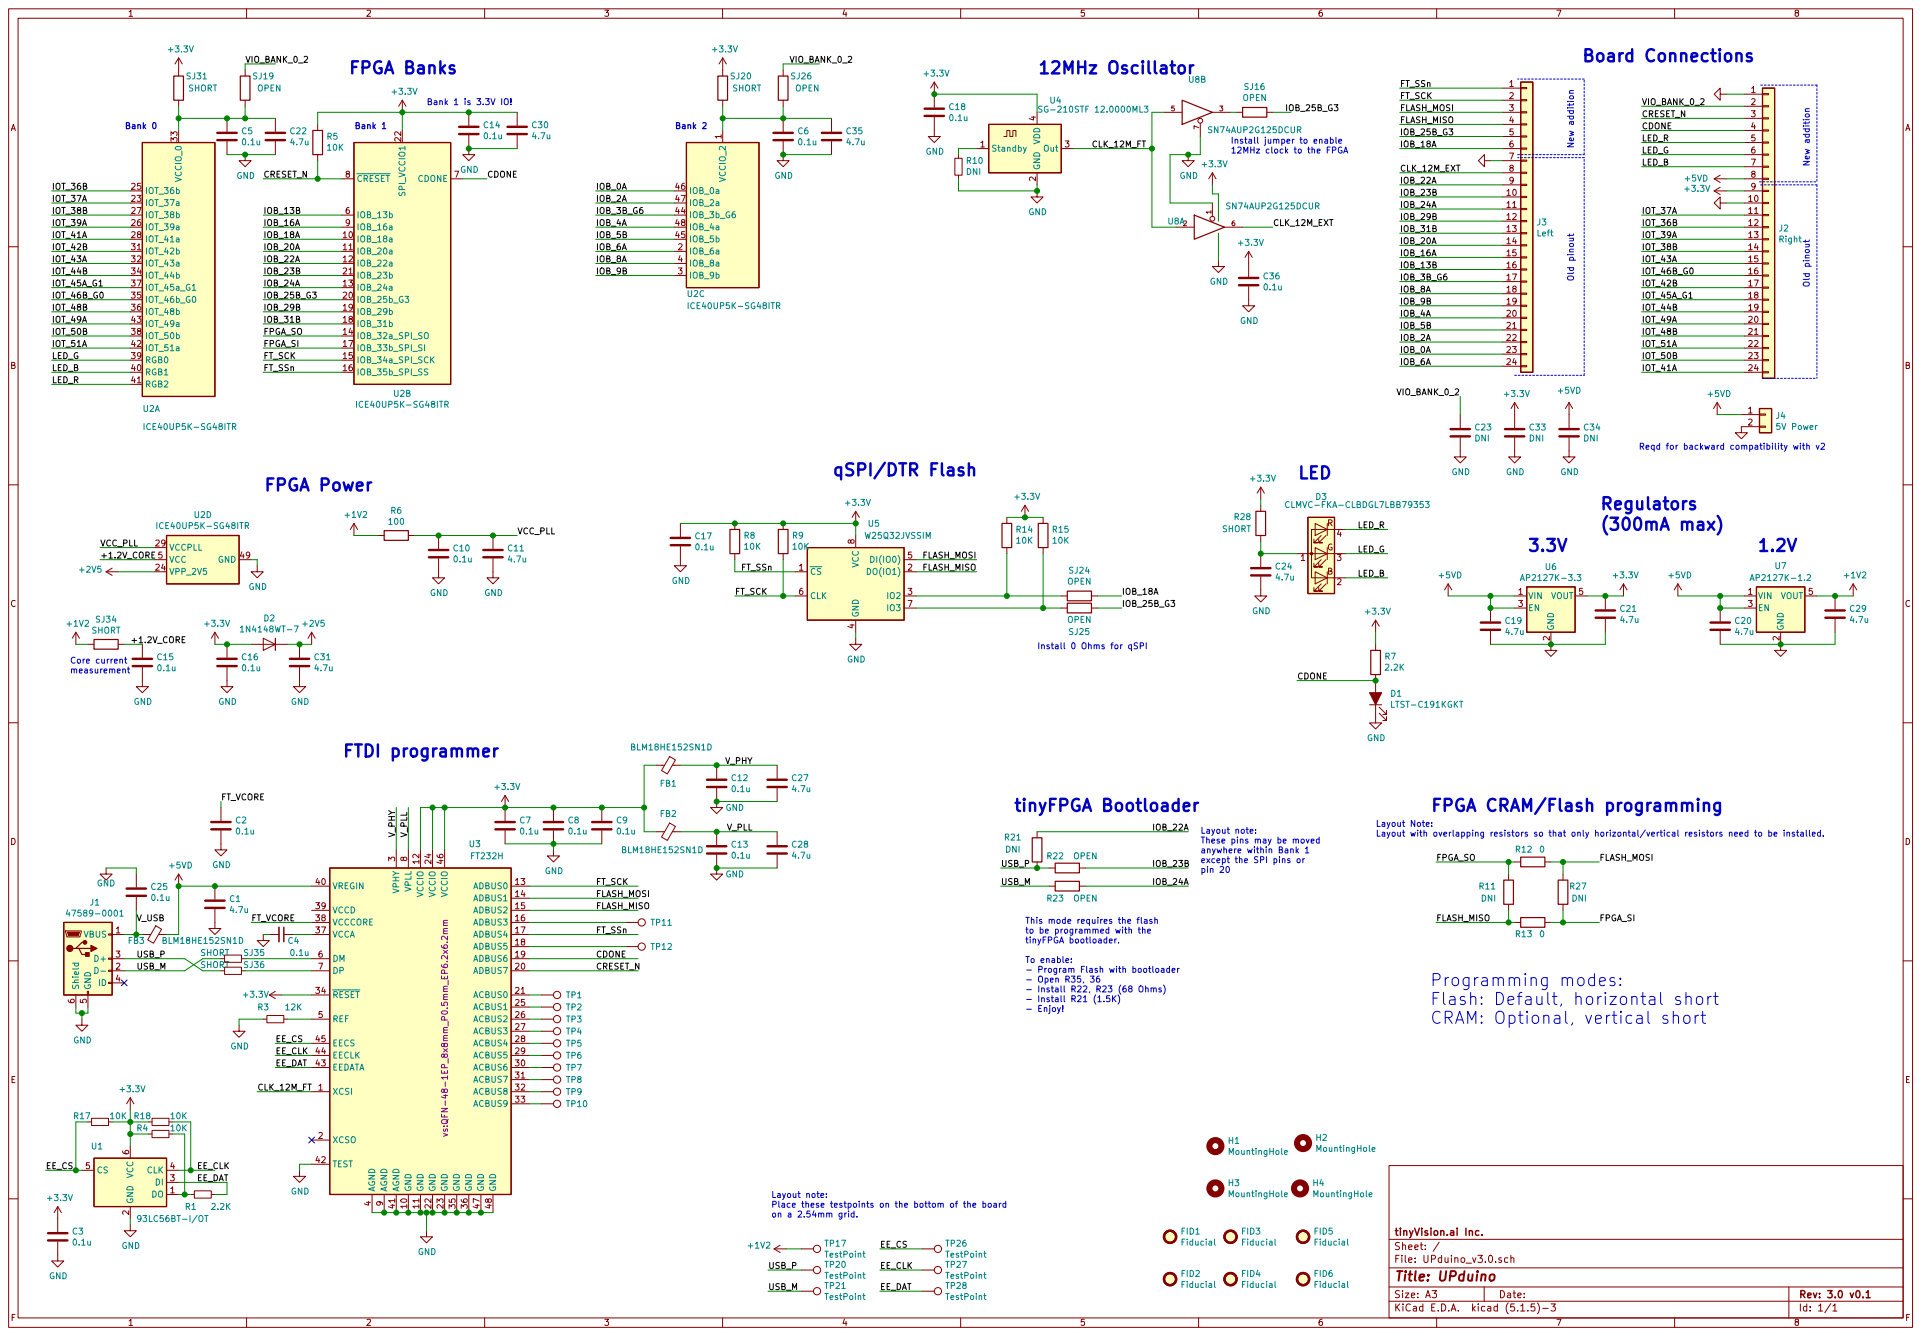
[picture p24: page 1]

Bank 1 is 3.3V IO! FTDI programmer

Install jumper to enable 12MHz clock to the FPGA

Install 0 Ohms for qSPI

Layout note:
These pins may be moved
anywhere within Bank 1
except the SPI pins or

Layout Note:
Layout with overlapping resistors so that only horizontal/vertical resistors need to be installed.

4 VREGIN 40 AGND 41 TEST 42 EEDATA 43 EECLK 44 EECS 45 VCCIO 46 GND 47 GND 48 REF 5 DM 6 DP 7 VPLL

3 ACBUS6 30 ACBUS7 31 ACBUS8 32 ACBUS9 33 RESET 34 GND 35 GND 36 VCCA 37 VCCCORE 38 VCCD 39 AGND

This mode requires the flash
to be programmed with the
tinyFPGA bootloader. To enable: - Program Flash with bootloader

Programming modes:
Flash: Default, horizontal short
CRAM: Optional, vertical short

2 DI 3 CLK 4 CS 5 VCC

Place these testpoints on the bottom of the board
on a 2.54mm grid.

File: UPduino_v3.0.sch Sheet: / tinyVision.ai Inc.

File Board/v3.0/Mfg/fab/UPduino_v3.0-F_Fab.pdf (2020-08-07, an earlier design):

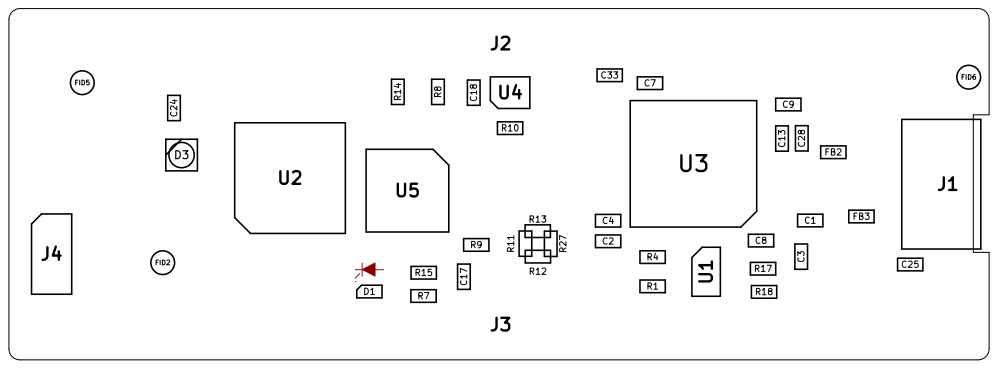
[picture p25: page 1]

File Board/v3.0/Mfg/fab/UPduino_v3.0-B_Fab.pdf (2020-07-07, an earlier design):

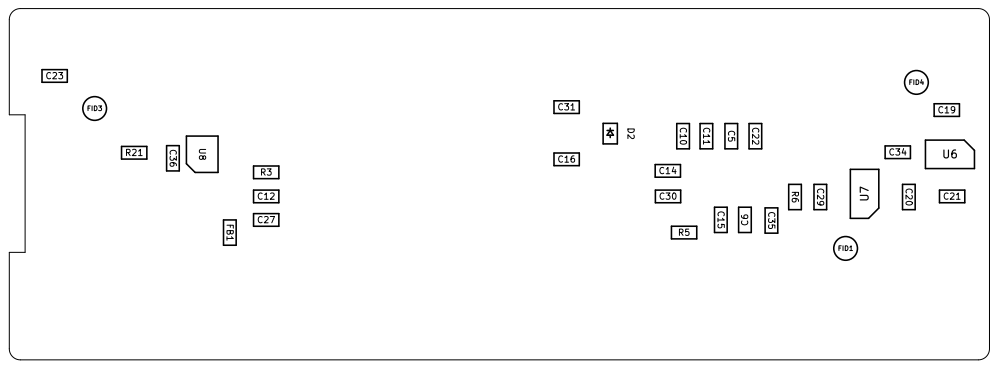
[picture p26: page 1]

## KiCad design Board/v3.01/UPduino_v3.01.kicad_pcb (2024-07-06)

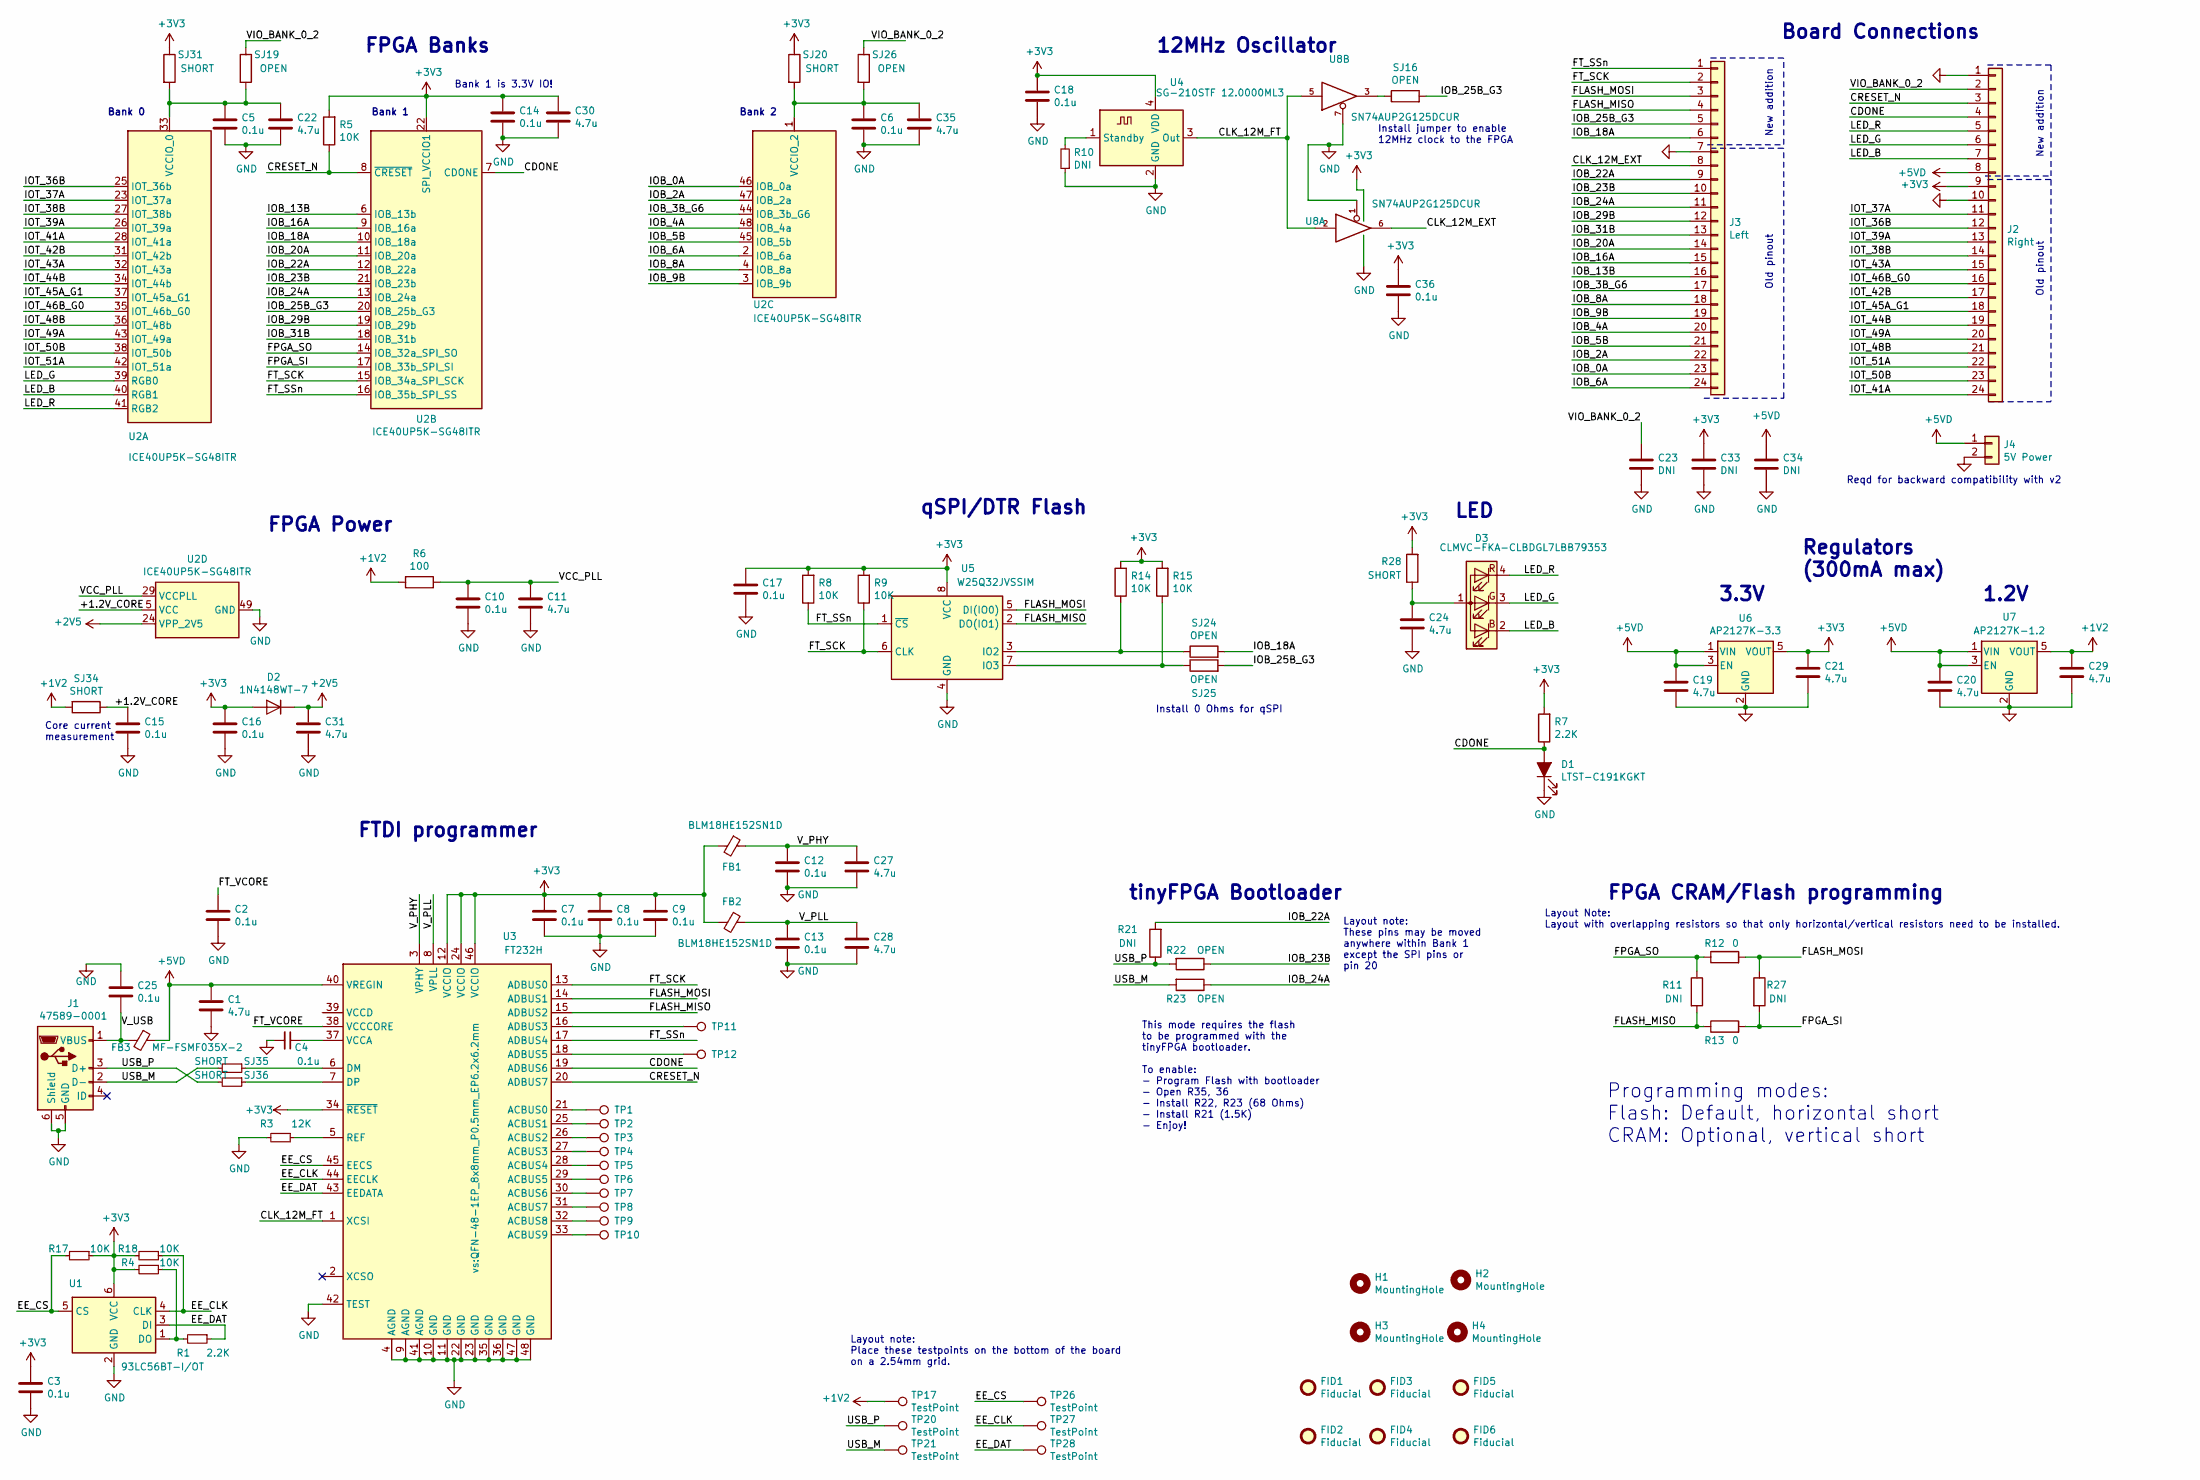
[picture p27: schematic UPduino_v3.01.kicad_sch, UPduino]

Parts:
C1, C11, C19, C20, C21, C22, C24, C27, C28, C29, C30, C31, C35: 4.7u; C_0603_1608Metric
C2, C3, C4, C6, C7, C8, C9, C10, C12, C13, C14, C15, C16, C17, C18, C25, C36: 0.1u; C_0603_1608Metric
C5: 0.1u; C_0603_1608Metric; MPN C1005X5R0J104K050BA
C23, C33, C34: DNI; C_0603_1608Metric
D1: LTST-C191KGKT; LED_0603_1608Metric
D2: 1N4148WT-7; D_SOD-523
D3: CLMVC-FKA-CLBDGL7LBB79353; LED_Cree-PLCC4_2x2mm_CW
FB1, FB2: BLM18HE152SN1D; L_0603_1608Metric
FB3: MF-FSMF035X-2; L_0603_1608Metric
FID1, FID2, FID3, FID4, FID5, FID6: Fiducial; Fiducial_0.75mm_Mask1.5mm
H1, H2, H3, H4: MountingHole; MountingHole_2.5mm_M3
J1: 47589-0001; USB_Micro_AB_Female_0475890001
J2: Right; PinHeader_1x24_P2.54mm_Vertical
J3: Left; PinHeader_1x24_P2.54mm_Vertical
J4: 5V Power; PinHeader_1x02_P2.54mm_Vertical
R1, R7: 2.2K; R_0603_1608Metric
R3: 12K; R_0603_1608Metric
R4, R5, R8, R9, R14, R15, R17, R18: 10K; R_0603_1608Metric
R6: 100; R_0603_1608Metric
R10, R11, R21, R27: DNI; R_0603_1608Metric
R12, R13: 0; R_0603_1608Metric
R22, R23: OPEN; SolderJumper-2_0603_Open_TrianglePad1.0x1.5mm
R28: SHORT; ShortedJumper-2_P1.3mm_Bridged_Pad1.0x1.0mm
SJ16, SJ19, SJ24, SJ25, SJ26: OPEN; SolderJumper-2_0603_Open_TrianglePad1.0x1.5mm
SJ20, SJ31, SJ34, SJ35, SJ36: SHORT; ShortedJumper-2_P1.3mm_Bridged_Pad1.0x1.0mm
TP1, TP2, TP3, TP4, TP5, TP6, TP7, TP8, TP9, TP10, TP11, TP12, TP17, TP20, TP21, TP26, TP27, TP28: TestPoint; TestPoint_Pad_D1.0mm
U1: 93LC56BT-I/OT; SOT-23-6
U2: ICE40UP5K-SG48ITR; QFN-48-1EP_7x7mm_P0.5mm_EP5.6x5.6mm
U3: FT232H; QFN-48-1EP_8x8mm_P0.5mm_EP6.2x6.2mm
U4: SG-210STF 12.0000ML3; Oscillator_SMD_Abracon_ASDMB-4Pin_2.5x2.0mm
U5: W25Q32JVSSIM; SOIC-8_5.23x5.23mm_P1.27mm
U6: AP2127K-3.3; SOT-23-5
U7: AP2127K-1.2; SOT-23-5
U8: SN74AUP2G125DCUR; VSSOP-8_2.3x2mm_P0.5mm

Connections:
+1V2: C29.1, R6.2, SJ34.2, TP17.1, U7.5 (VOUT)
+2V5: C31.1, D2.1 (K), U2.24 (VPP_2V5)
+3V3: C3.1, C7.1, C8.1, C9.1, C14.1, C16.1, C17.1, C18.1, C21.1, C30.1, C33.1, C36.1, D2.2 (A), FB1.2, FB2.2, J2.9, R4.2, R5.2, R7.2, R8.2, R9.2, R14.2, R15.2, R17.1, R18.2, R28.2, SJ20.1, SJ31.1, U1.6 (VCC), U2.22 (SPI_VCCIO1), U3.12 (VCCIO), U3.24 (VCCIO), U3.34 (~RESET), U3.46 (VCCIO), U4.4 (VDD), U5.8 (VCC), U6.5 (VOUT), U8.8 (VCC)
+5VD: C1.1, C19.1, C20.1, C34.1, FB3.1, J2.8, J4.1, U3.40 (VREGIN), U6.1 (VIN), U6.3 (EN), U7.1 (VIN), U7.3 (EN)
/+1.2V_CORE: C15.1, SJ34.1, U2.5 (VCC), U2.30 (VCC)
/CDONE: D1.2 (A), J2.4, R7.1, U2.7 (CDONE), U3.19 (ADBUS6)
/CLK_12M_EXT: J3.8, U8.6
/CLK_12M_FT: U3.1 (XCSI), U4.3 (Out), U8.2, U8.5
/CRESET_N: J2.3, R5.1, U2.8 (~CRESET), U3.20 (ADBUS7)
/EE_CLK: R18.1, TP27.1, U1.4 (CLK), U3.44 (EECLK)
/EE_CS: R17.2, TP26.1, U1.5 (CS), U3.45 (EECS)
/EE_DAT: R1.1, TP28.1, U1.3 (DI), U3.43 (EEDATA)
/FLASH_MISO: J3.4, R11.2, R13.1, U3.15 (ADBUS2), U5.2 (DO(IO1))
/FLASH_MOSI: J3.3, R12.2, R27.1, U3.14 (ADBUS1), U5.5 (DI(IO0))
/FPGA_SI: R13.2, R27.2, U2.17 (IOB_33b_SPI_SI)
/FPGA_SO: R11.1, R12.1, U2.14 (IOB_32a_SPI_SO)
/FT_SCK: J3.2, R9.1, U2.15 (IOB_34a_SPI_SCK), U3.13 (ADBUS0), U5.6 (CLK)
/FT_SSn: J3.1, R8.1, U2.16 (IOB_35b_SPI_SS), U3.17 (ADBUS4), U5.1 (~CS)
/FT_VCORE: C2.1, U3.38 (VCCCORE)
/IOB_0A: J3.23, U2.46 (IOB_0a)
/IOB_2A: J3.22, U2.47 (IOB_2a)
/IOB_3B_G6: J3.17, U2.44 (IOB_3b_G6)
/IOB_4A: J3.20, U2.48 (IOB_4a)
/IOB_5B: J3.21, U2.45 (IOB_5b)
/IOB_6A: J3.24, U2.2 (IOB_6a)
/IOB_8A: J3.18, U2.4 (IOB_8a)
/IOB_9B: J3.19, U2.3 (IOB_9b)
/IOB_13B: J3.16, U2.6 (IOB_13b)
/IOB_16A: J3.15, U2.9 (IOB_16a)
/IOB_18A: J3.6, SJ24.2, U2.10 (IOB_18a)
/IOB_20A: J3.14, U2.11 (IOB_20a)
/IOB_22A: J3.9, R21.2, U2.12 (IOB_22a)
/IOB_23B: J3.10, R22.1, U2.21 (IOB_23b)
/IOB_24A: J3.11, R23.1, U2.13 (IOB_24a)
/IOB_25B_G3: J3.5, SJ16.2, SJ25.2, U2.20 (IOB_25b_G3)
/IOB_29B: J3.12, U2.19 (IOB_29b)
/IOB_31B: J3.13, U2.18 (IOB_31b)
/IOT_36B: J2.12, U2.25 (IOT_36b)
/IOT_37A: J2.11, U2.23 (IOT_37a)
/IOT_38B: J2.14, U2.27 (IOT_38b)
/IOT_39A: J2.13, U2.26 (IOT_39a)
/IOT_41A: J2.24, U2.28 (IOT_41a)
/IOT_42B: J2.17, U2.31 (IOT_42b)
/IOT_43A: J2.15, U2.32 (IOT_43a)
/IOT_44B: J2.19, U2.34 (IOT_44b)
/IOT_45A_G1: J2.18, U2.37 (IOT_45a_G1)
/IOT_46B_G0: J2.16, U2.35 (IOT_46b_G0)
/IOT_48B: J2.21, U2.36 (IOT_48b)
/IOT_49A: J2.20, U2.43 (IOT_49a)
/IOT_50B: J2.23, U2.38 (IOT_50b)
/IOT_51A: J2.22, U2.42 (IOT_51a)
/LED_B: D3.2 (RK), J2.7, U2.40 (RGB1)
/LED_G: D3.3 (GK), J2.6, U2.39 (RGB0)
/LED_R: D3.4 (BK), J2.5, U2.41 (RGB2)
/USB_M: J1.2 (D-), R23.2, SJ35.2, TP21.1
/USB_P: J1.3 (D+), R21.1, R22.2, SJ36.2, TP20.1
/VCC_PLL: C10.1, C11.1, R6.1, U2.29 (VCCPLL)
/VIO_BANK_0_2: C23.1, J2.2, SJ19.1, SJ26.1
/V_PHY: C12.1, C27.1, FB1.1, U3.3 (VPHY)
/V_PLL: C13.1, C28.1, FB2.1, U3.8 (VPLL)
/V_USB: C25.2, FB3.2, J1.1 (VBUS)
GND: C1.2, C2.2, C3.2, C4.2, C5.2, C6.2, C7.2, C8.2, C9.2, C10.2, C11.2, C12.2, C13.2, C14.2, C15.2, C16.2, C17.2, C18.2, C19.2, C20.2, C21.2, C22.2, C23.2, C24.2, C25.1, C27.2, C28.2, C29.2, C30.2, C31.2, C33.2, C34.2, C35.2, C36.2, D1.1 (K), J1.5 (GND), J1.6 (Shield), J2.1, J2.10, J3.7, J4.2, R3.2, R10.1, U1.2 (GND), U2.49 (GND), U3.4 (AGND), U3.9 (AGND), U3.10 (GND), U3.11 (GND), U3.22 (GND), U3.23 (GND), U3.35 (GND), U3.36 (GND), U3.41 (AGND), U3.42 (TEST), U3.47 (GND), U3.48 (GND), U4.2 (GND), U5.4 (GND), U6.2 (GND), U7.2 (GND), U8.1, U8.4 (GND), U8.7
unnamed: C4.1, U3.37 (VCCA)
unnamed: C5.1, C22.1, SJ19.2, SJ31.2, U2.33 (VCCIO_0)
unnamed: C24.1, D3.1 (A), R28.1
unnamed: C6.1, C35.1, SJ20.2, SJ26.2, U2.1 (VCCIO_2)
unnamed: R1.2, R4.1, U1.1 (DO)
unnamed: R3.1, U3.5 (REF)
unnamed: R10.2, U4.1 (Standby)
unnamed: R14.1, SJ24.1, U5.3 (IO2)
unnamed: R15.1, SJ25.1, U5.7 (IO3)
unnamed: SJ16.1, U8.3
unnamed: SJ35.1, U3.6 (DM)
unnamed: SJ36.1, U3.7 (DP)
unnamed: TP1.1, U3.21 (ACBUS0)
unnamed: TP2.1, U3.25 (ACBUS1)
unnamed: TP3.1, U3.26 (ACBUS2)
unnamed: TP4.1, U3.27 (ACBUS3)
unnamed: TP5.1, U3.28 (ACBUS4)
unnamed: TP6.1, U3.29 (ACBUS5)
unnamed: TP7.1, U3.30 (ACBUS6)
unnamed: TP8.1, U3.31 (ACBUS7)
unnamed: TP9.1, U3.32 (ACBUS8)
unnamed: TP10.1, U3.33 (ACBUS9)
unnamed: TP11.1, U3.16 (ADBUS3)
unnamed: TP12.1, U3.18 (ADBUS5)

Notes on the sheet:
FPGA Banks
FPGA Power
Install jumper to enable 12MHz clock to the FPGA
Layout note: Place these testpoints on the bottom of the board on a 2.54mm grid.
New addition
Layout Note: Layout with overlapping resistors so that only horizontal/vertical resistors need to be installed.
Programming modes: Flash: Default, horizontal short CRAM: Optional, vertical short
Board Connections
Bank 2
Reqd for backward compatibility with v2
Old pinout
Layout note: These pins may be moved anywhere within Bank 1 except the SPI pins or pin 20
tinyFPGA Bootloader
Core current measurement
Install 0 Ohms for qSPI
1.2V
Bank 1
LED
qSPI/DTR Flash
FTDI programmer
3.3V
FPGA CRAM/Flash programming
This mode requires the flash to be programmed with the tinyFPGA bootloader. To enable: - Program Flash with bootloader - Open R35, 36 - Install R22, R23 (68 Ohms) - Install R21 (1.5K) - Enjoy!
Regulators (300mA max)
12MHz Oscillator
Bank 0
Bank 1 is 3.3V IO!

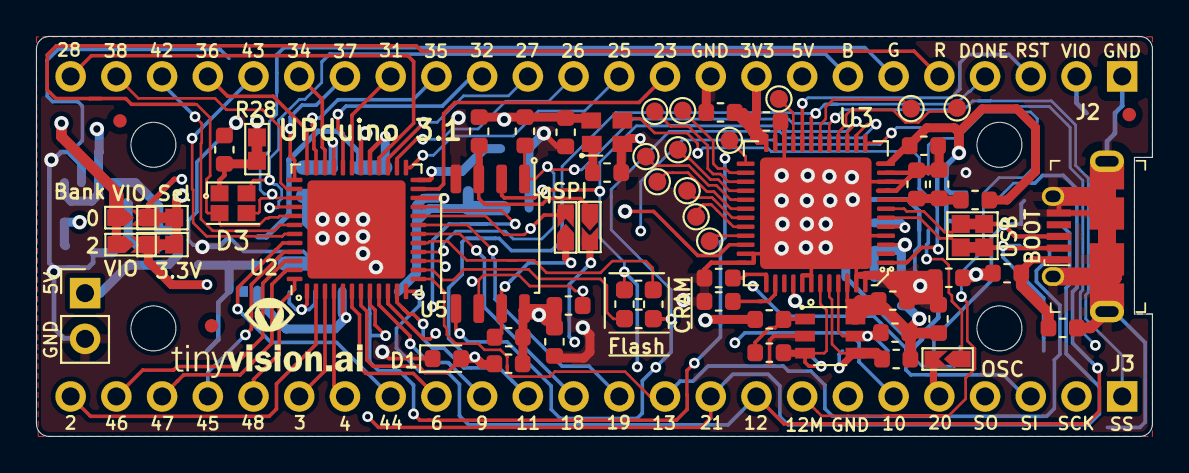
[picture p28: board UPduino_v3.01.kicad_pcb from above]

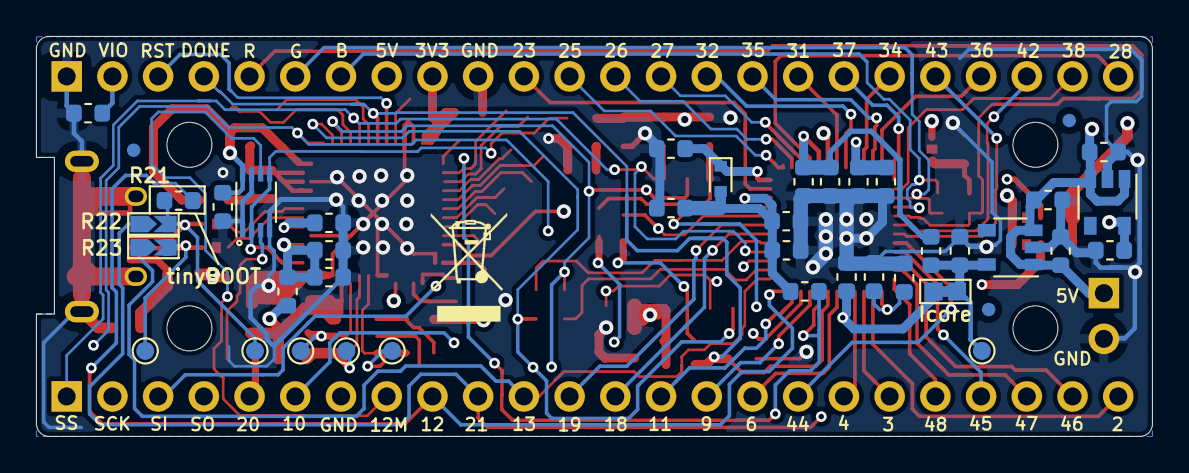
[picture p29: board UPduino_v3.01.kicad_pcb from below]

Board: 4 copper layers, 62.0 x 22.2 mm, 111 parts (41 on the bottom side), 86 nets.

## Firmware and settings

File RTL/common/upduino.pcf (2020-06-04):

# The LED pins are on dedicated pins and cannot be modified!
# Note that they are negative logic (write a 0 to turn on).
# These are also brought out to the left side of the board. 
# Cut the board trace on jumper R28 to disable the onboard 3 color LED.
set_io -nowarn led_green 39
set_io -nowarn led_red	41
set_io -nowarn led_blue	40

# FTDI chip interface
set_io -nowarn serial_txd 14 # FPGA transmit to USB
set_io -nowarn serial_rxd 15 # FPGA receive from USB
set_io -nowarn spi_cs 16 # Connected to SPI flash, drive high unless using SPI flash!

# If using the FTDI MPSSE engine, the following signals apply
set_io -nowarn spi_sck 15  # Shared with the flash
set_io -nowarn spi_ssn 16  # Connected to SPI flash, drive high unless using SPI flash!
set_io -nowarn spi_mosi 17 # Shared with the flash
set_io -nowarn spi_miso 14 # Shared with the flash

# Normal GPIO pins, left side
set_io -nowarn gpio_23 23
set_io -nowarn gpio_25 25
set_io -nowarn gpio_26 26
set_io -nowarn gpio_27 27
set_io -nowarn gpio_32 32
set_io -nowarn gpio_35 35
set_io -nowarn gpio_31 31
set_io -nowarn gpio_37 37
set_io -nowarn gpio_34 34
set_io -nowarn gpio_43 43
set_io -nowarn gpio_36 36
set_io -nowarn gpio_42 42
set_io -nowarn gpio_38 38
set_io -nowarn gpio_28 28

# Normal GPIO pins, right side

# Following pins are added on the v3.0 of the board.
# SPI pins are brought out to the right side of the board

# Note: On board 12MHz clock can be brought to IOB_25B_G3 (pin 20) which is a global
# clock input. Short across R16 (labelled OSC on the board) to enable 12MHz clock to
# pin 20.
set_io -nowarn gpio_20 20
set_io -nowarn gpio_10 10

# Following are also found on v2.x of the UPduino
set_io -nowarn gpio_12 12
set_io -nowarn gpio_21 21
set_io -nowarn gpio_13 13
set_io -nowarn gpio_19 19
set_io -nowarn gpio_18 18
set_io -nowarn gpio_11 11
set_io -nowarn gpio_9 9
set_io -nowarn gpio_6 6
set_io -nowarn gpio_44 44
set_io -nowarn gpio_4 4
set_io -nowarn gpio_3 3
set_io -nowarn gpio_48 48
set_io -nowarn gpio_45 45
set_io -nowarn gpio_47 47
set_io -nowarn gpio_46 46
set_io -nowarn gpio_2 2

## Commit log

2019-11-18 Initial version of schematic
    Thanks to Raffi for all the input!
    [UPduino.kicad_pcb, UPduino.sch]
2019-11-18 Updated with missing symbols
    [UPduino.sch]
2019-11-19 Updated with input from Lattice
    - Changed diode dropper to create 2.5V to 1N4148, added decoupling cap after that
    - Added 5V header
    - Added zero ohm jumper to measure core power consumption
    - No cascading of LDO's
    - Added 1.8V regulator and output to the board pins
    [UPduino.sch]
2019-11-19 Minor edits
    - Added jumpers to USB_P/M to allow the tinyFPGA programmer to work
    - Minor text changes
    [UPduino.sch]
2019-11-20 More changes!
    Programming scheme finalized
    Schematic cleanup
    [UPduino.kicad_pcb, UPduino.sch]
2019-12-03 Updated with latest schematics and layout
    [UPduino.kicad_pcb, UPduino.sch]
2019-12-09 Updated schematic
2019-12-23 Final CAD
    [BoM_UPduino.csv, UPduino.kicad_pcb, UPduino.sch]
2019-12-24 Fixed MISO/MOSI bug
    PDF schematic update only! Rest of the design will be updated soon.
2019-12-26 Fixed mosi/miso bug, added silkscreen changes
    [UPduino.kicad_pcb, UPduino.sch]
2020-03-17 Final version
    [BOM.xlsx, UPduino.kicad_pcb, UPduino_SoM.sch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]
2020-03-17 Post merge cleanup
    [BOM.xlsx, UPduino.kicad_pcb]
2020-03-20 Update UPduino_v3.0.kicad_pcb
    Fixed duplicate silkscreen (pin 35->36) on IOT48B connection
    [UPduino_v3.0.kicad_pcb]
2020-03-25 Cleaned up silkscreen, created new gerbers
    [UPduino_SoM.sch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]
2020-03-26 Fixed lost library references. Edited schematic file by hand to resolve horrible name mangling
    [UPduino_v3.0.sch]
2020-04-12 Added v2 to address changes from v1
    [BoM_UPduino.csv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]
2020-04-12 Changed diode footprint, LED, modified FTDI reset, silkscreen for board and a few other changes
    [UPduino_v3.0.kicad_pcb, UPduino_v3.0.sch]
2020-05-11 Fixed silkscreen, removed CRAM/Flash programming switch
    [UPduino_v3.0.kicad_pcb, UPduino_v3.0.sch]
2020-05-12 Added BoM to the zipfile
2020-05-12 Added BoM
    [UPduino_v3.csv]
2020-05-26 Added fab drawings
    [UPduino_v3.0.kicad_pcb]
2020-06-04 Minor edits to clean up PDC and FPGA build flow
2020-06-06 Fixed RGB LED bug
    [UPduino_v3.0-B_CrtYd.gbr, UPduino_v3.0-B_Mask.gbs, UPduino_v3.0-B_Paste.gbp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]
2020-06-08 Added board images
2020-06-08 Fixed assembly drawing link
2020-06-08 Removed CE logo, added RoHS logo, regenerated gerbers.
    [UPduino_v3.0-B_CrtYd.gbr, UPduino_v3.0-B_Mask.gbs, UPduino_v3.0-B_Paste.gbp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]
2020-06-09 Fixed pass/fail criteria for 3.3V and LED
2020-07-06 Updated gerbers and fab files
    [UPduino_v3.0-B_CrtYd.gbr, UPduino_v3.0-B_Cu.gbl, UPduino_v3.0-B_Mask.gbs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]
2020-07-07 Bugfix for 12MHz clock pin
    @ggrummer identified a bug that the 12MHz clock and ground pins are swapped.
    [UPduino_v3.0-B_CrtYd.gbr, UPduino_v3.0-B_Cu.gbl, UPduino_v3.0-B_Mask.gbs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]
2020-07-07 Regenerated gerbers
    [UPduino_v3.0-B_CrtYd.gbr, UPduino_v3.0-B_Cu.gbl, UPduino_v3.0-B_Mask.gbs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]
2020-07-07 Removed reference to C26 in schematic notes for tinyFPGA bootloader mode
    Thanks to @ggrummer
    [UPduino_v3.0.sch]
2020-07-09 Added country of origin USA on back silkscreen
    [UPduino_v3.0-B_CrtYd.gbr, UPduino_v3.0-B_Cu.gbl, UPduino_v3.0-B_Mask.gbs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]
2020-07-11 Fixed DRC by assigning FTDI pad to ground which it wasnt for some reason!
    [UPduino_v3.0.kicad_pcb]
2020-07-27 Modified silkscreen and updated gerbers. Used for final production run
    [UPduino_v3.0-B_CrtYd.gbr, UPduino_v3.0-B_Cu.gbl, UPduino_v3.0-B_Mask.gbs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]
2020-08-06 3 color LED disconnect docs
2020-08-06 Changed R and B ports in schematic symbol for the 3 color LED, thanks to Pablo Cossutta
2020-08-07 Added clarification of LED orientation on the fab drawing
2020-08-11 Changed schematic to reflect shorted and open jumpers
    [UPduino_v3.0.kicad_pcb, UPduino_v3.0.sch]
2020-09-08 Added assembly file
2020-12-13 UPduino Lattice Radiant and Reveal v2.2 example project and Soft JTAG demo --- whf
    [rgb_blinky_rgb_blinky_imp_vo.sdf]
2020-12-14 Minimal design with all pins for power testing
2020-12-14 Moved directories
    [rgb_blinky_rgb_blinky_imp_vo.sdf]
2020-12-14 Removed implementation files
    [rgb_blinky_rgb_blinky_imp_vo.sdf]
2021-04-27 Restored to the older text drawing and fixed the pinout for the 12MHz/Ground issue
2021-04-27 Fixed global clock pin allocation and added note about qSPI mode
2022-01-02 Changed pin 25 from gpio_24 to gpio_2
    Thanks to @riz
2022-04-24 Added Icestudio link
    also provided brief explanation as to the necessity of installing dev branch/nightly build of icestudio as current release doesn't have upduino 3.1 in boards list.
2022-05-29 cleaned up the language and increased readability
    Patronics Patch (#1)
    * Fix broken links
    they were internal rather than external links, so just led to 404s
    * add an additional resource, the examples from XarkLabs
    This example has other valuable resources like guides on simulation, pullup resistors, validation, etc.
    authored-by: Patrick Leiser <patrick27leiser@yahoo.com>
2022-05-29 Minor edits (#21)
    * Patronics Patch (#1)
    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
2024-07-06 Fixed schematic bug on EEPROM, this was only on the SCH and not in the PDF or the board.
    [UPduino_v3.01.kicad_pcb, UPduino_v3.01.kicad_sch]
